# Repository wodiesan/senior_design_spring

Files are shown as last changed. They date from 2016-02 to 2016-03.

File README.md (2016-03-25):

<p align="center">
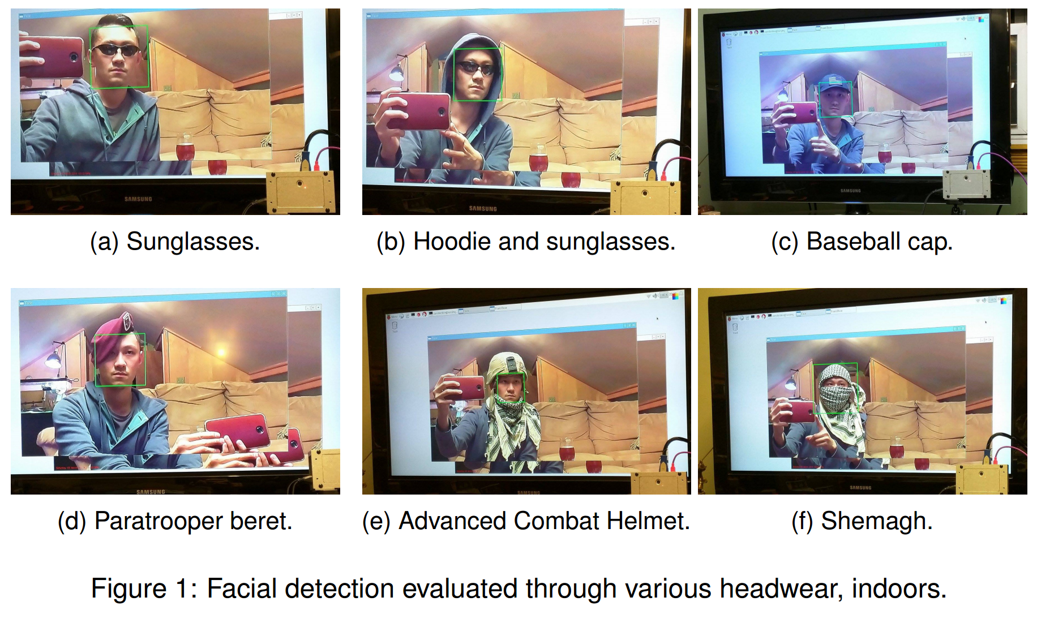
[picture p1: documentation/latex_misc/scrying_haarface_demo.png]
Scrying Logo
  
</p>

# Scrying
A computer vision home surveillance system based on the Raspberry Pi 2. Utilizes the Raspberry Pi CSI camera module and OpenCV framework.

## Front matter
Origin: Senior Electronic Design I Project, Spring 2016  
Advisor: Professor Scott Grenquist  
Deptartment: Electrical Engineering and Technology  
College: Wentworth Institute of Technology  

### What is Scrying?
A low-cost, low-maintenance, Raspberry Pi 2-based home surveillance 
system. This system is designed to allow a homeowner to record digital 
footage. The system includes basic object detection. Recorded videos will
be cataloged by the object type that activated the camera, e.g. human, 
vehicle, and others. The result is a lightweight and scalable home 
surveillance system that remains inexpensive in storage.

#### Main file
The main file is ``scrying.py`` in [scrying](https://github.com/wodiesan/senior_design_spring/tree/master/scrying).

#### Documentation
Visit [documentation](https://github.com/wodiesan/senior_design_spring/tree/master/documentation) for details. All of the technical documents from the semester&mdash;including LaTeX source code&mdash;are in this directory.
The order of the submissions:  

1. [Proposal](https://github.com/wodiesan/senior_design_spring/blob/master/documentation/ChauSze_SeniorDesign1_ProposalRev2.pdf)
2. [Calculations](https://github.com/wodiesan/senior_design_spring/blob/master/documentation/ChauSze_SeniorDesign1_CalcRev2.pdf)
3. [Prototype](https://github.com/wodiesan/senior_design_spring/blob/master/documentation/ChauSze_SeniorDesign1_PrototypeRev1.pdf)
4. Manufacturing: *In progress.*

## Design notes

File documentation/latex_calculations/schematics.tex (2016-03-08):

\section{Schematics}
\label{sec:schem}

\subsection{ATtiny85 Design: First Iteration}
\begin{figure}[H]
    \centering
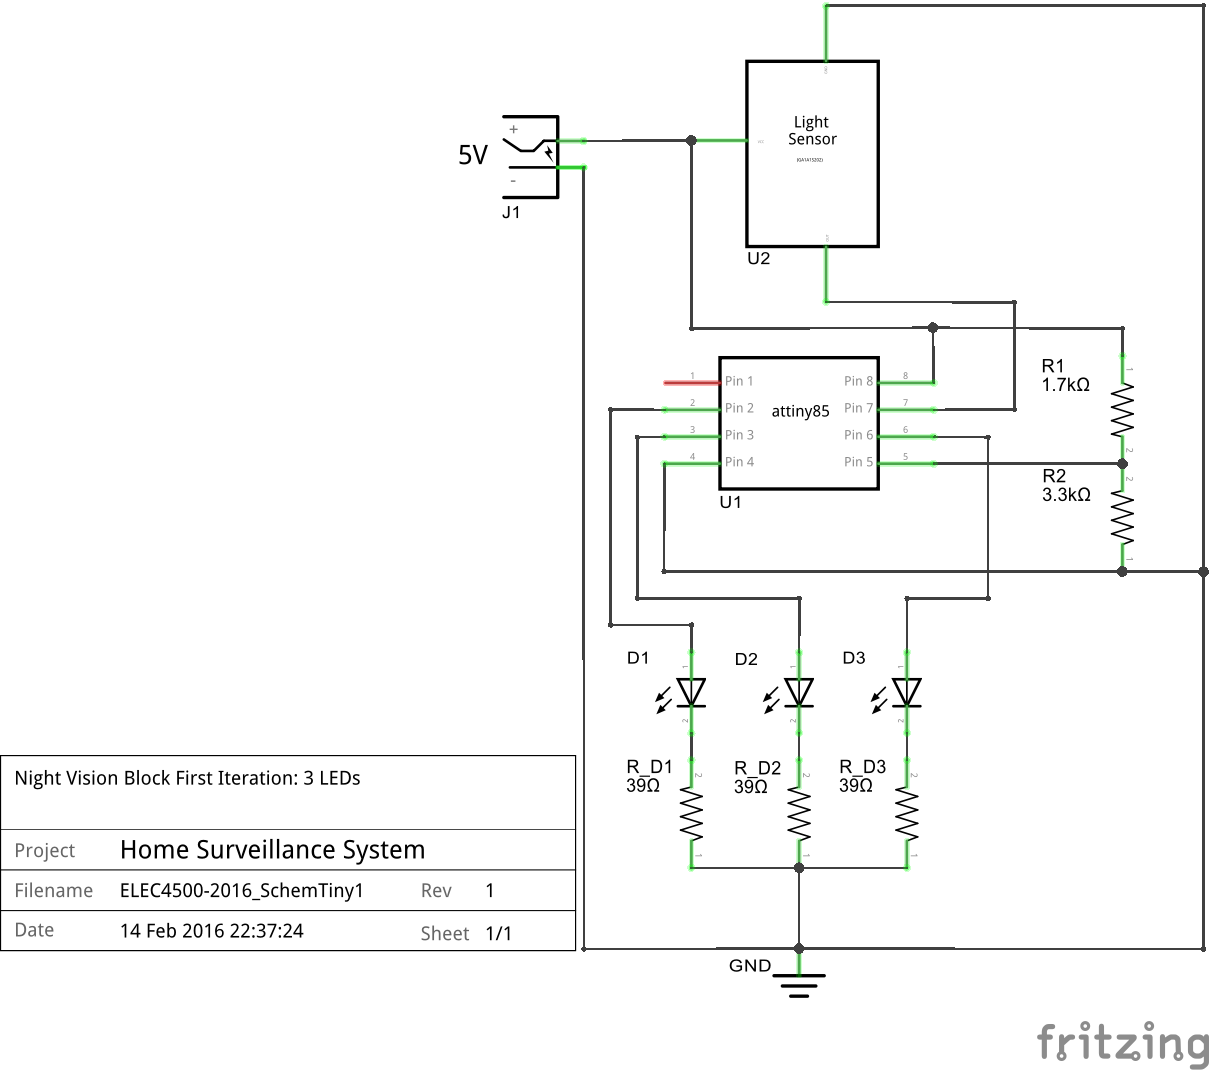
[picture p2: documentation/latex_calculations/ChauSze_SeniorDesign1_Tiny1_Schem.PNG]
    \makebox[\textwidth][c]{}
    \caption{Fritzing schematic of the first ATtiny85 design.}
    \label{tiny1_schem}
\end{figure}

\subsection{ATtiny85 Design: Second Iteration}
\begin{figure}[H]
    \centering
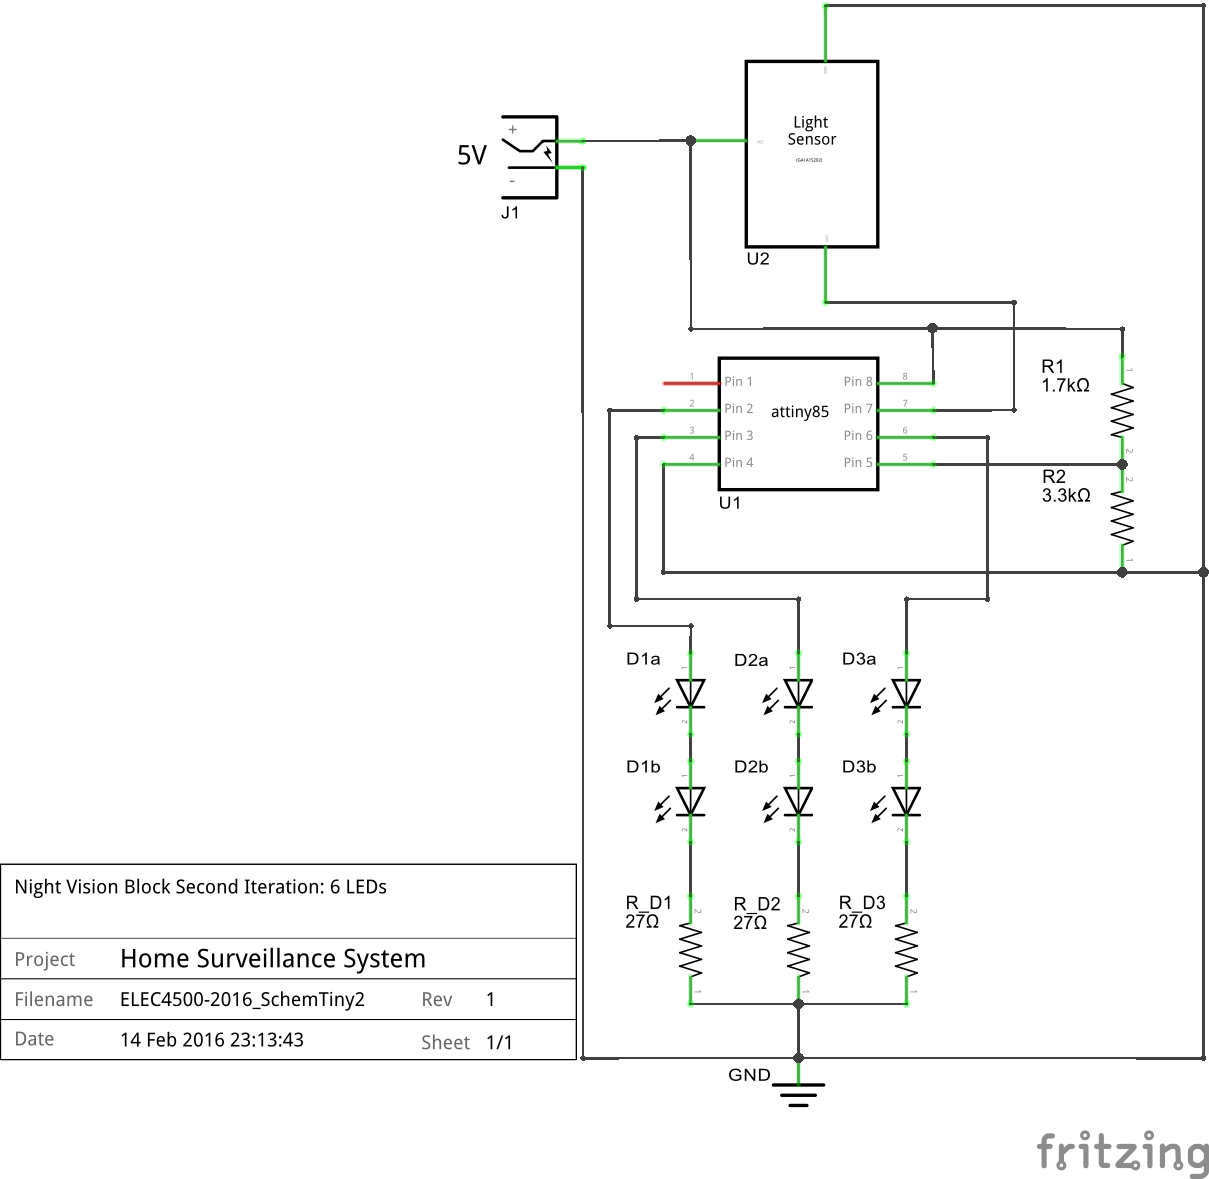
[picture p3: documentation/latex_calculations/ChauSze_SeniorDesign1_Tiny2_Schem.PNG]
    \makebox[\textwidth][c]{}
    \caption{Fritzing schematic of the second ATtiny85 design.}
    \label{tiny2_schem}
\end{figure}

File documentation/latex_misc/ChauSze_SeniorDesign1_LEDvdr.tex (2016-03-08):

\documentclass{article}
\usepackage{tikz}
\usepackage{circuitikz}
\usepackage{siunitx}

\begin{document}
\begin{circuitikz}
\draw (0,2.2)node[anchor=north]{ATtiny85 Pin}
    (0,1.8)node[anchor=north]{5V}
    (0,1)
    node[rground, yscale=-1]{}
    %node[anchor=east] {ATtiny85 Pin: 5V}%(5,0.5) 
    (0,1) -- (0,0)
    to [R={\parbox{1cm}{$R_{IR}$\\\SI{27}{\ohm}}}, mirror] (3,0)
    to [empty led,l_=$LED_{IR}$] (5,0)
    to [empty led,l_=$LED_{IR}$] (7,0)
    (7,0) -- (8,0)
    to (8,-1) node[ground]{};
    
\draw (0,-3)node[anchor=north]{$V_{CC}$}
    (0,-3.4)node[anchor=north]{5V}
    (0,-4.2)
    node[rground, yscale=-1]{}
    to [R={\parbox{1cm}{$R_{1}$\\\SI{1.7}{\kilo\ohm}}}, mirror] (0, -6)
    to[short, -*](0,-6.5)
    to [R={\parbox{1cm}{$R_{2}$\\\SI{3.3}{\kilo\ohm}}}, mirror] (0, -9)
    to (0,-9) node[ground]{}
    (0,-6.5)to[short,-o](-2,-6.5) node[anchor=east]{$V_{o}$};
\end{circuitikz}
\end{document}

%\usepackage[american voltages,siunitx]{circuitikz}

%\begin{document}

%\begin{circuitikz}
%   \draw (0,0) to [R={\parbox{1cm}{$R_{IR}$\\\SI{39}{\ohm}}}, mirror]  (3,0);  
%   \draw (3,0) to [empty led,l=IR] (5,0);
%  \draw (0,-0.5) -- node[anchor=north,align=center] {\SI{5}{V}  \\ ATtiny85 Pin } (0,0.5);
%  \draw (5,-0.5) --  node[anchor=south] {VCC} (5,0.5)  node[anchor=west] {\SI{5}{V}};
%\end{circuitikz}

%\end{document}

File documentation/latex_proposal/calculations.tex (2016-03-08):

\section*{Calculations}
\label{sec:calc}
% CHANGE GB TO 1073741824 BYTES!!!

\subsection{Storage}

Storage requirements for 24 hours of 720p video data (.mp4):
\begin{equation*}
\begin{split}
Continual & = \left(\frac{24 \ hr}{1 \ day}\right)\left(\frac{60 \ min}{1 \ hr}\right)\left(\frac{60 \ sec}{ 1 \ min}\right)\left(\frac{17 \ mbit}{1 \ sec}\right)\left(\frac{1 \ byte}{8 \ bit}\right)\left(\frac{1 \ GB}{1737441824 \ byte}\right) \\
& = 170.99 \ \frac{GB}{day}
\end{split}
\end{equation*}

By limiting the active recording to moments where objects are detected, this storage requirement can be significantly lowered. Taking a theoretical family of 4 and a single dog, we can calculate for a minimum duration that the RPi2 is expected to record in 24 hours: 

\begin{table}[H]
\centering
\caption{Known \glspl{sighting} during an average 24 hour day for a front door camera.}
\label{floor_table}
\begin{tabular}{@{}lcccc@{}}
\toprule
Type     & Qty & Duration (min) & Sighting/24 hr & Total  \\ \midrule
Person   & 4   & 1              & 2               & 8      \\
Dog      & 1   & 1              & 2               & 2      \\
Delivery & 2   & 1              & 1               & 2      \\ \midrule
         &     &                &                 & 12 min
\end{tabular}
\end{table}

With a minimum recording duration of 12 minutes based on the expected sightings (detected objects), the floor data requirements per 24 hours becomes:

\begin{equation*}
\begin{split}
Floor \ & = \left(\frac{12 \ min}{1 \ day}\right)\left(\frac{60 \ sec}{ 1 \ min}\right)\left(\frac{17 \ Mbit}{1 \ sec}\right)\left(\frac{1 \ byte}{8 \ bit}\right)\left(\frac{1 \ GB}{1737441824 \ byte}\right) \\
& = 0.000014254 \ \frac{GB}{day}\Rightarrow 0.014254 \ \frac{MB}{day} \Rightarrow 14.254 \ \frac{KB}{day}
\end{split}
\end{equation*}

\subsection{Analog Light Sensor}

\begin{equation*}
\begin{split}
    \log\left(I_{O}\right) &= mx + b \\
    I_{O} &= m\log\left(x\right) + b \\
    I_{O} &= 10\log\left(E_{v}\right)\left[l_{x}\right]
\end{split}
\end{equation*}

The sensor has an output current range of $0\mu A$--$50\mu A$ between $1$ lux--$100000$ lux. The breakout board converts this current into a voltage using a $68K\Omega$ resistor, giving a voltage output of $0V$--$3.4V$. Given the use-case of the light sensor, the $3.4V$ can be approximated to $3.3V$, which is a suitable voltage reference for the RPi2. With the output current range approximated to a voltage range of $0V$--$3.3V$ between $1$ lux--$100000$ lux,

\begin{equation*}
\begin{split}
    log_{i} &= \log\left(l_{x \ MAX} - l_{x \ MIN}\right) \\
    &= \log\left(100000\right) = 5 \\
\end{split}
\end{equation*}

To convert the analog value to a digital value, an 8-bit ADC is used:
\begin{equation*}
    ADC = \frac{log_{i}}{1024 \ steps} = 0.00488
\end{equation*}

Finally, the formula to obtain the final lux output, $l_{xo}$, on the RPi2:

\begin{equation*}
%\begin{split}
    l_{xo} = 10^{raw_{i} \times ADC} = 10^{raw_{i} \times 0.00488}
%\end{split}
\end{equation*}

where $raw_{i}$ is the raw value received by the ADC connected to the RPI2's GPIO.

%\newpage

%\begin{multicols}{2}
%\begin{onehalfspacing}
%\printglossary
%\end{onehalfspacing}
%\end{multicols}

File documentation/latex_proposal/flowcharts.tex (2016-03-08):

\section*{Flowcharts}
\label{sec:flow}
\begin{figure}[H]
    \centering
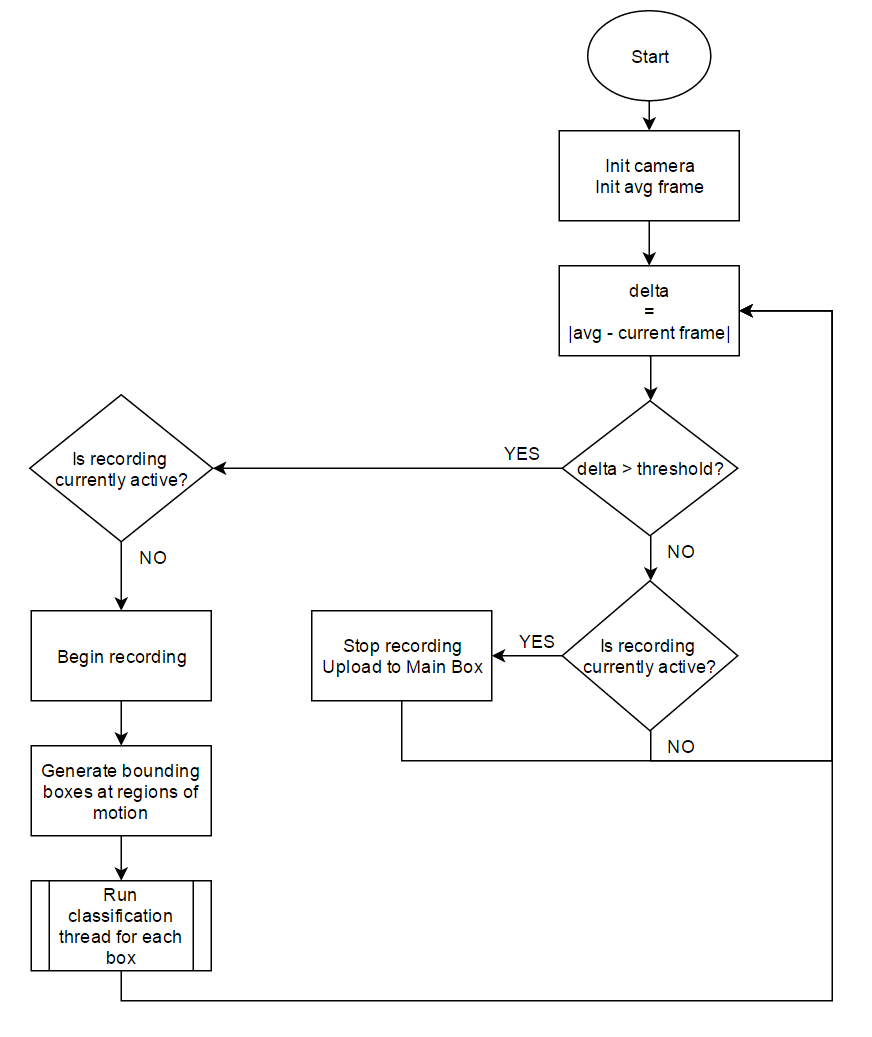
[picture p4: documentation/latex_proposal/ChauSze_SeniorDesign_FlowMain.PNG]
    \makebox[\textwidth][c]{}
    \caption{Flowchart of main program.}
\end{figure}

\begin{figure}[H]
    \centering
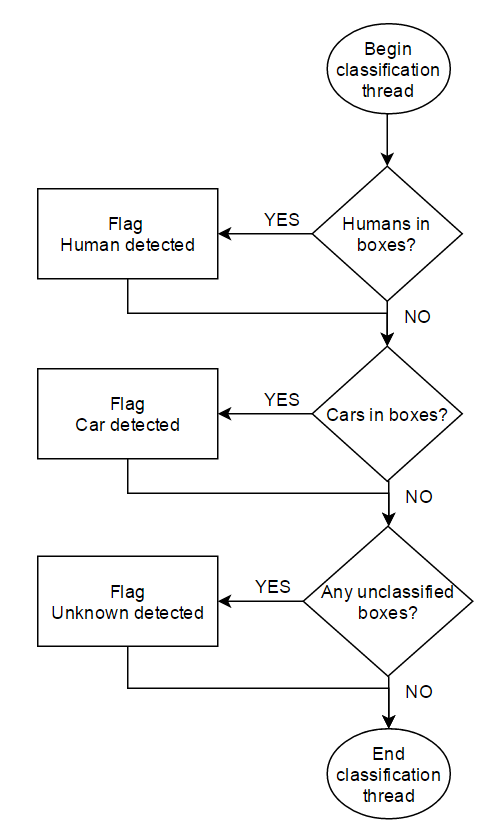
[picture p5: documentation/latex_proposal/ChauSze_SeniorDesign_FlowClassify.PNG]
    \makebox[\textwidth][c]{}
    \caption{Flowchart of classification thread.}
\end{figure}

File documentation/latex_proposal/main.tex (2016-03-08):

\documentclass[12pt]{article}
%\usepackage{fontspec}
%\usepackage[utf8]{inputenc}

\usepackage[margin=1in]{geometry}

\usepackage{graphicx}
\usepackage{amsmath}
\usepackage{float}
\usepackage{xfrac}
\usepackage{subfig}
\captionsetup{belowskip=12pt,aboveskip=4pt}
\usepackage{booktabs}
\usepackage{enumitem}
\usepackage{csquotes}

\usepackage{amsmath}
\usepackage{mathptmx}
\usepackage{helvet}
\renewcommand{\familydefault}{\sfdefault}
\usepackage{verbatim}
\usepackage{gensymb}
\usepackage{setspace}
\usepackage{booktabs}
\usepackage{hyperref}

\usepackage{listings}
\usepackage{color}
\definecolor{lightgrey}{rgb}{0.9,0.9,0.9}
\definecolor{darkgreen}{rgb}{0,0.6,0}

\usepackage{fancyhdr}
\pagestyle{fancy}
\cfoot{Confidential $\mid$ ELEC4500--2016 Rev. 3}
\rfoot{\thepage}

\usepackage{multicol} % Required for splitting text into multiple columns
\setlength{\columnsep}{1cm}
\usepackage[toc]{glossaries}
\usepackage[protrusion=true,expansion=true]{microtype} % Improves spacing
%\usepackage[bf,sf,center]{titlesec} % Required for modifying section titles - bold, sans-serif, centered
%\usepackage{fancyhdr} % Required for modifying headers and footers
%\usepackage{subfiles}

\usepackage[toc,page]{appendix}

\makeglossaries
\input{./glossary.tex}

\begin{document}\thispagestyle{empty}
\pagenumbering{gobble}
\input{./title.tex}
\titleTMB
\newpage
\doublespacing

%\documentclass[12pt]{article}
%\usepackage{graphicx}
%\usepackage{float}
%\usepackage{chngpage}
%\addtolength{\topmargin}{-.5in}
%\textheight = 650pt
%\usepackage{helvet}
%\renewcommand{\familydefault}{\sfdefault}

%\begin{document}

%----------------------------------------------------------------------
% ECO
%----------------------------------------------------------------------
%\vspace{5in}
\begin{table}[H]
\centering
\caption{Revision history.}
\label{table_rev}
\begin{tabular}{@{}llcc@{}}
\toprule
\multicolumn{2}{c}{Senior Electronic Design Proposal}                                                          & \multicolumn{2}{c}{Document Number: ELEC4500--2016} \\ \midrule
Rev. & \multicolumn{1}{l}{Description of Change}                                                               & \S $\ $ Affected & \multicolumn{1}{c}{Originator}   \\
     &                                                                                                         &                  &                                  \\
01   & Initial Release                                                                                         & All              & N. Bamford, R. Chau, A. Martinez \\
     &                                                                                                         &                  &                                  \\
02   & \begin{tabular}[c]{@{}l@{}}General Proofreading\\ Add Glossary and Calculations\\ Add Fig. 6--9, Tbl. \ref{software_req}\\ Revise Fig. 5, Sec. 6, \& References \end{tabular} & All              & R. Chau                          \\
     &                                                                                                         &                  &                                  \\
03   & \begin{tabular}[c]{@{}l@{}}Revise Calculations and Progress Chart\\ Add Flowcharts and Schematics \end{tabular} & All              & N. Bamford, R. Chau, A. Martinez                          \\ \bottomrule
\end{tabular}
\end{table}

\newpage

%----------------------------------------------------------------------
% Abstract and Table of Contents
%----------------------------------------------------------------------
\begin{abstract}\thispagestyle{empty}

A low-cost, low-maintenance, Raspberry \Gls{Pi} 2-based home surveillance system is proposed in this document. This system is designed to allow a homeowner to record digital footage--through low-ambient environments--when a motion threshold is surpassed. The system will include basic human \gls{detection} and object \gls{recognition} features. Recorded videos will be cataloged by the object type that activated the camera, e.g. human, vehicle, and others. This proposed functionality will allow a homeowner to quickly access the database of footage through categorical ``bookmarks'' based on metadata such as date, time, and type of object. The result is a lightweight and scalable home surveillance system that remains inexpensive for storage. 

\end{abstract}

\newpage

\tableofcontents

\newpage

\listoffigures

\listoftables

\newpage

%---------------------------------------------------------------------
% Intro
%---------------------------------------------------------------------
\pagenumbering{arabic}
\section{Problem Statement and Motivation}

Newton, Massachusetts is constantly rated as one of the safest cities in the country; that doesn't mean that crime doesn't occur in the city \cite{newton}. At a localized point of view, one of the engineers on this project--a resident of Newton--accumulated numerous experiences that required the actions of Newton Police Department.  In 2015, the neighbor of this engineer had their house broken into. Thieves kicked in the back door; no one noticed the incident. A few months later, Newton Police was called upon to dust (for fingerprints) a family member’s work van after it was broken into for tools. On the week of Christmas, the garage of another neighbor was broken into overnight. This neighbor was restoring a classic muscle car, and the progress was halted due to stolen rare parts. The worst incident, however, happened a few years ago to the engineer’s friend that was--at the time--living in West Newton. It was a home invasion where the homeowner was tied up at gunpoint, and the thieves tossed her dog into a closet before leaving with jewelry and a safe. To this day the perpetrators were never caught.

The constraints of this device, as determined by informal surveying of Newton homeowners, include the ability to determine if there is an object in motion near a home entrance and to capture a video if this criteria is met. A secondary requirement requested asks for the design of a method to distinguish a human from other objects such as vehicles, and to create a metadata sorting method based on these identification criteria alongside date/time.

The design must take these traits into consideration, or else the system would be severely handicapped and similar to existing commercial systems. The proposed home surveillance system acts as an affordable, mobile, and open source bridge between available, albeit expensive commercial products that either secures empty homes or monitor internal dwellings.

\section{Background}

Literary research for this design split into two distinct avenues: Computer vision and  a novelty investigation into currently available commercial solutions.

\subsection{Computer Vision}

The development of an image processing technique that fits our objectives involves object \gls{recognition} within the field of computer vision. Computer vision is the science of imagery acquisition and interpretation through the use of computers \cite[p.~1-5]{cv}. Object \gls{recognition} describes the task of locating, or recognizing, specific objects within images. In the case of our design, object \gls{recognition} tasks could be incorporated to evaluate initial images arriving from a camera unit for identification of humans or vehicles. The object \gls{recognition} methods that are currently being considered includes \gls{Haar}-like features and \gls{Blob} \gls{detection}.

\subsubsection{Haar-like Features}

\gls{Haar}-like features gets their namesake due to similarities to \gls{Haar} wavelet transforms. It is an object \gls{recognition} algorithm that seeks out common patterns by calculating spatial relationships of information (such as contrast) of the target object \cite[p.~1]{haar}. These patterns that the \gls{Haar}-like algorithm checks are rectangular features that specific objects all have, such as the distance between a human’s eyes, or nose. As human \gls{recognition} is an important feature in the proposed system, a \gls{Haar}-based facial \gls{detection} algorithm will be investigated for the prototype.

\begin{figure}[H]
    \centering
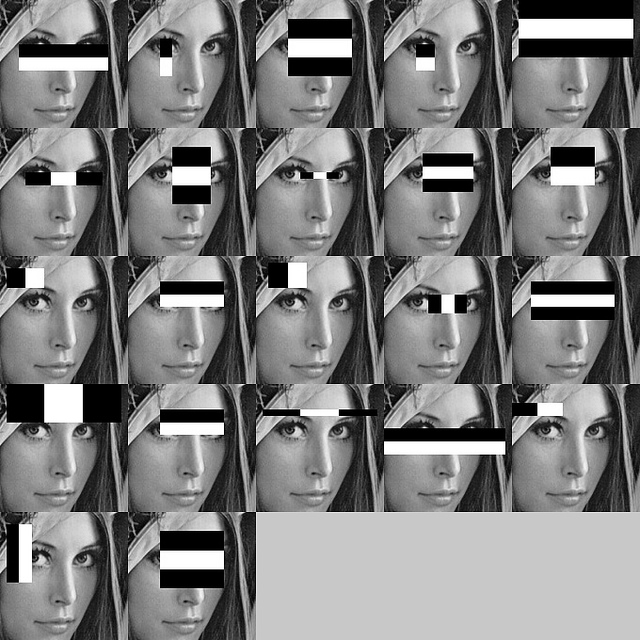
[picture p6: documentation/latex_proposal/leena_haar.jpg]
    \makebox[\textwidth][c]{}
    \caption{\gls{Haar}-like cascade algorithm used to detect human faces.}
\end{figure}

\subsubsection{Blob Detection and Analysis}

\Gls{Blob}s refer to regions of similar pixels in an image. Blob algorithms locates these regions and assigns a category to it based on light or color values \cite[p.~8-18]{blob}. This method requires segmentation of the target image, which involves in the removal of everything outside the region of interest. Depending on the target environment, \gls{Blob} analysis is subject to noise in the form of mis-categorized \gls{Blob}s. The deployment of a \gls{Blob} analysis algorithm would require significant pre-processing of our target object. The advantage of utilizing \gls{Blob} \gls{detection}, however, includes simple identification of large, single-color dominant objects such as vehicles. Due to this capability, \gls{Blob} \gls{detection} will be one of the algorithms used for the prototype. Of concern is the dependability of \gls{Blob} \gls{detection} during low ambient conditions.

%\subsubsection{Other Computer Vision Methods}
% Other potential computer vision methods--such as feature detection methods--will be investigated.

\subsection{Novelty Investigation}

The investigation focused on three major companies with home monitoring commercial solutions. Verizon and Comcast have indoor and outdoor cameras that provide a wireless security system capable with live stream alongside phone apps. This is something that the team aims to pursue (time-dependent). For the proposed system, it is important that the final design remains cost efficient, and the main feature to implement--object \gls{detection} alongside an alert system--is something that current commercial products haven't introduced to the market. Looking at companies that supply commercial home surveillance systems, the team wanted to identify: 

\begin{singlespace}

\begin{itemize}
    \item Patterns of features.
    \item Whether the plan comes with a subscription.
    \item Installation cost, if any.
    \item Cost of the physical equipment.
\end{itemize}

\end{singlespace}

\subsubsection{Verizon}

Verizon offers a home security camera using the brand Canary, a 1080p HD camera able to live stream real time video and audio via a laptop or an app (requires 1 Mbps upload) \cite{verizon}. The camera is equipped with automatic night vision able to viewable with a 25 feet range. The camera is capable of motion \gls{detection} which can be activated and start recording once it senses movement. The sensors are a 3-axis accelerometer with ambient light and capacitive touch. Verizon does not require a personal installation contractor, the camera is an easy 1-2-3 set up and doesn't require a subscription fee.  The app is compatible with IPhone running iOS 7 and higher, and Android 4.0. Cost for everything is \$200 which includes camera, microusb cable, guide, and setup cable.

\begin{figure}[H]
    \centering
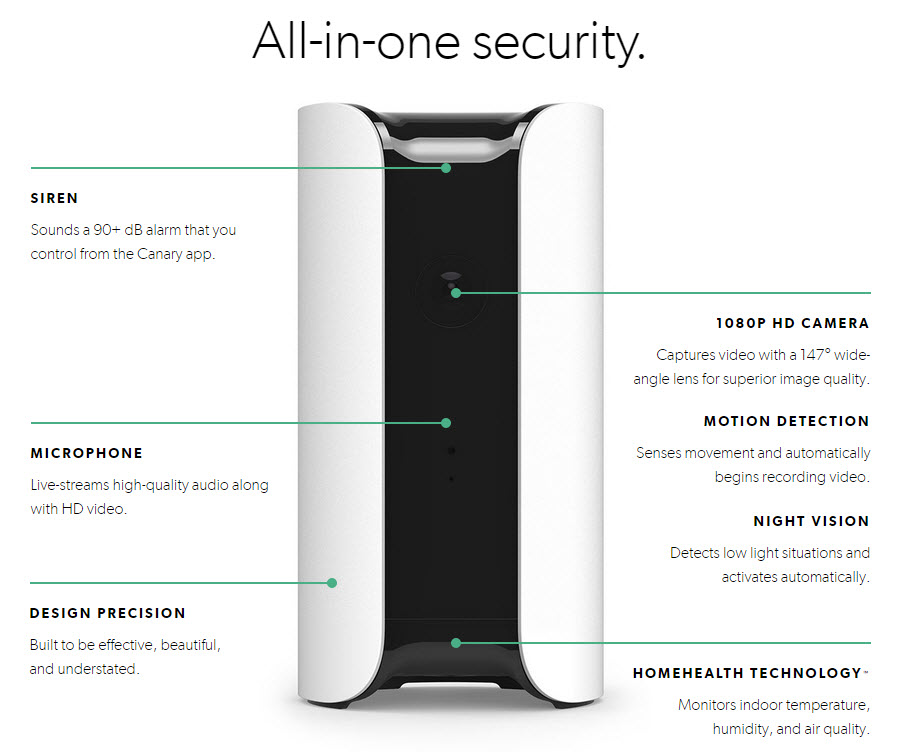
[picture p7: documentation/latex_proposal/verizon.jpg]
    \makebox[\textwidth][c]{}
    \caption{Verizon Canary system.}
\end{figure}

\subsubsection{Comcast}

Comcast Xfinity Homes offers a home security camera that seems to be smaller in size but is able to be placed outside of your house since it is more weather-proof \cite{comcast}. The camera's features are 720p HD resolution, it has night vision although not specified of the range, supports wifi and has sensor motion as well. Although the features for the camera are vague, it comes with a custom tablet and a keypad where you can control the camera. It is optional to use an app on your phone or a laptop to view live video monitoring in and outside your home. For the pricing, the equipment will cost \$200 not including the \$99 installation fee (depending on where you live). Then there is the subscription fee of \$30 a month, which makes the total cost in a range between \$300 to \$400.

\begin{figure}[H]
    \centering
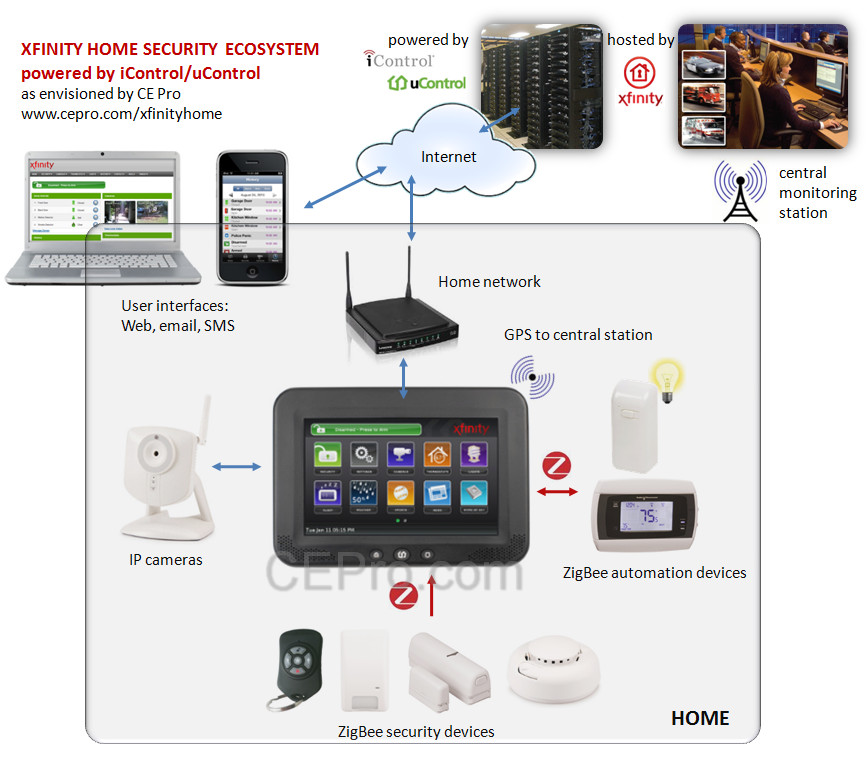
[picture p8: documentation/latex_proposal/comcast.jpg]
    \makebox[\textwidth][c]{}
    \caption{Comcast Xfinity Homes system.}
\end{figure}

\subsubsection{ADT}

ADT Security offers a home surveillance camera called the ADT Pulse Camera, it's a wireless day/night camera \cite{adt}. The camera is equipped with video motion \gls{detection}, a light sensor for night vision, and the camera can capture images that can be viewed online. The security system use their own encrypted wifi accessed through WPA2. The downfall of this camera is you are not able to deliver or store audio when recording the device. The device is also capable of high/low temperature monitoring, light control, climate control, small appliance management and remote access. When it comes to the pricing the installation charge is \$99, comes with a 3 year monitoring agreement that is \$36.99 per month, which is an added total of \$1,331.64. 

\begin{figure}[H]
    \centering
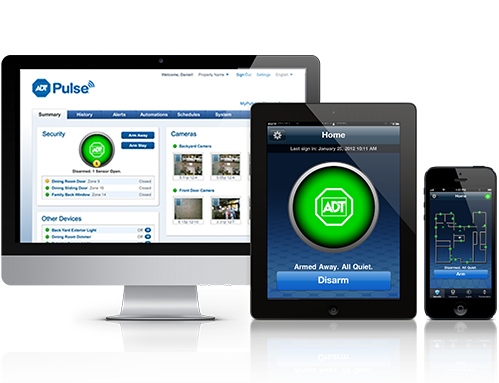
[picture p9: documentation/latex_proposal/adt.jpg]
    \makebox[\textwidth][c]{}
    \caption{ADT Pulse system.}
\end{figure}

\section{Proposed Solution}

\begin{figure}[H]
    \centering
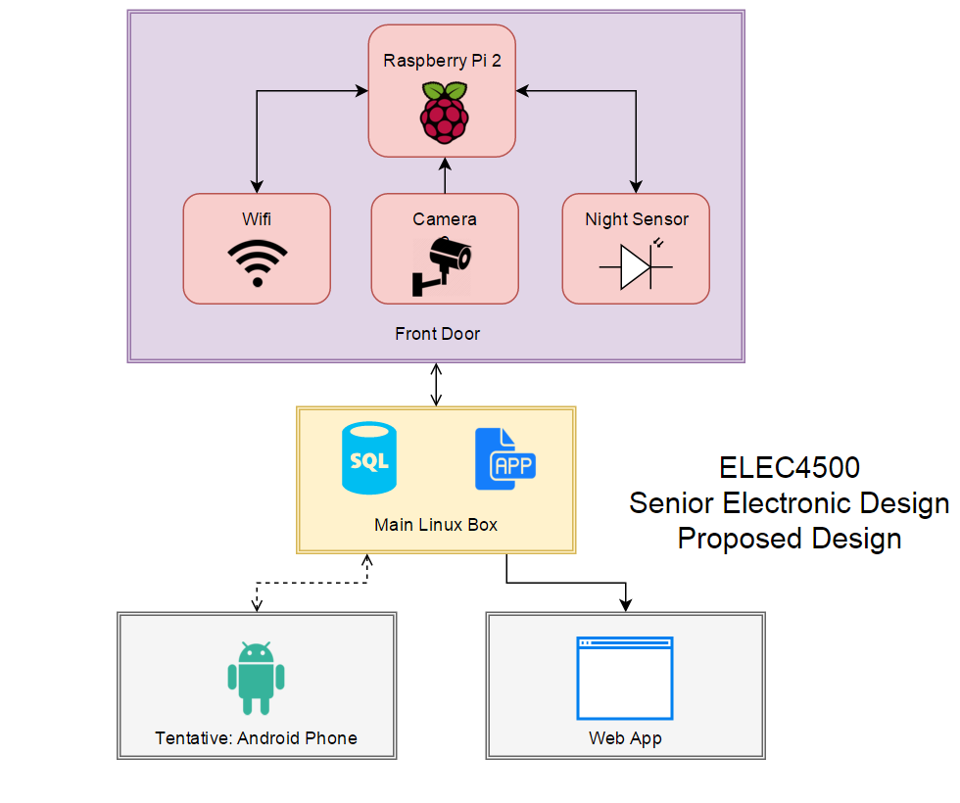
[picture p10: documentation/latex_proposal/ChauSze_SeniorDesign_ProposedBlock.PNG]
    \makebox[\textwidth][c]{}
    \caption{High level block diagram of proposed monitoring system.}
\end{figure}

\begin{table}[H]
\centering
\caption{Minimum software requirements for proposed solution.}
\label{software_req}
\begin{tabular}{@{}lllll@{}}
\toprule
Technology & Version & Type                              & License                    \\ \midrule
Raspbian   & Jessie  & Raspberry Pi Linux OS Distro      & GPLv2                      \\
Debian     & Jessie  & Desktop Linux OS Distro           & DFSG-Compliant             \\
Apache     & 2.4.18  & Web Server                        & Apache 2.0                 \\
MySQL      & 5.7.11  & Relational DB Management System   & GPLv2                      \\
Python     & 2.7     & General Purpose Language          & Python Software Foundation \\
OpenCV     & 3.0.0   & Computer Vision Library           & BSD                        \\
Plotly     & 1.9.5   & Data Visualization Python Library & MIT                        \\ \bottomrule
\end{tabular}
\end{table}

\subsection{Website Mockups}
\begin{figure}[H]
    \centering
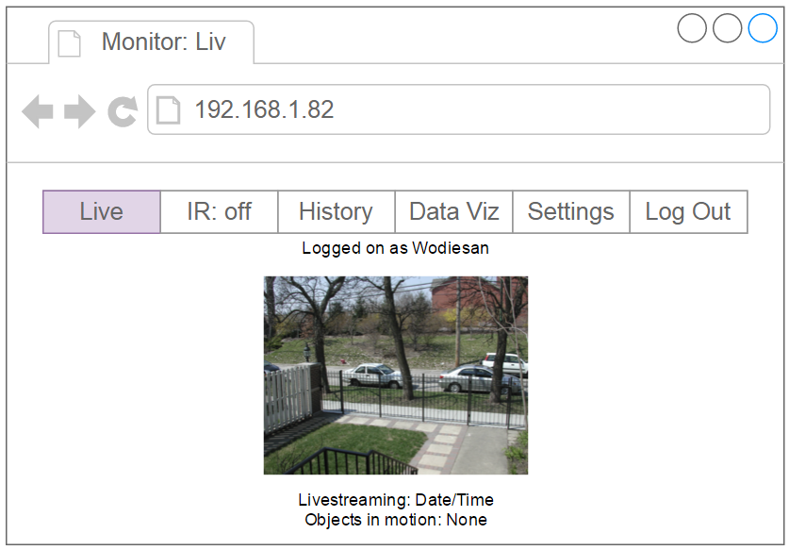
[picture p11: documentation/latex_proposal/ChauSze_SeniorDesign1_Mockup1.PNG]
    \makebox[\textwidth][c]{}
    \caption{Website mockup: \gls{livestream}, daytime.}
\end{figure}

\begin{figure}[H]
    \centering
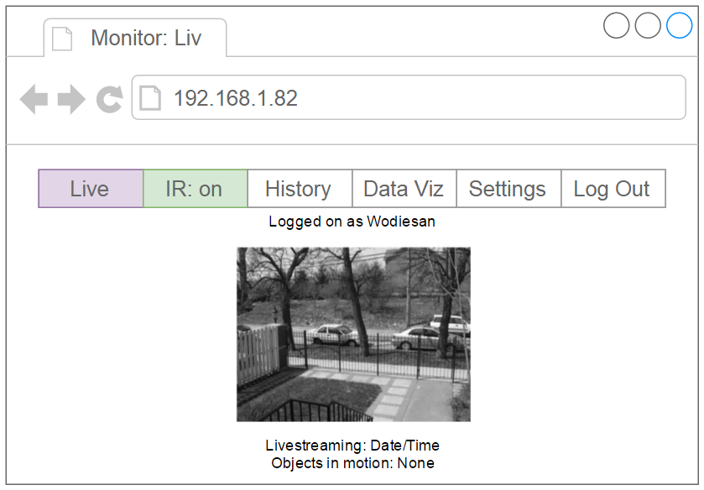
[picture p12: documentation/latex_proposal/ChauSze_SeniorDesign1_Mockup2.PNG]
    \makebox[\textwidth][c]{}
    \caption{Website mockup: \gls{livestream}, nighttime.}
\end{figure}

\begin{figure}[H]
    \centering
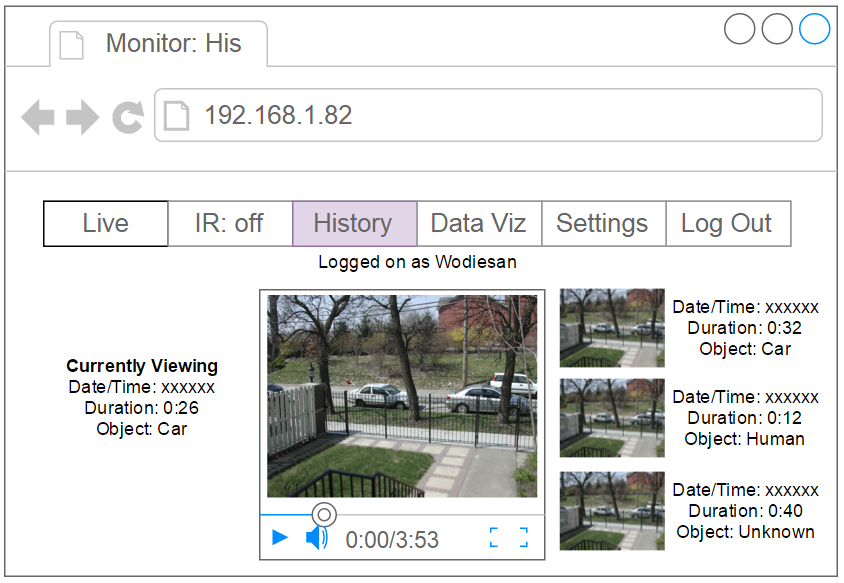
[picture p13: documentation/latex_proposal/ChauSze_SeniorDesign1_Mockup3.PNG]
    \makebox[\textwidth][c]{}
    \caption{Website mockup: History of detected objects.}
\end{figure}

\begin{figure}[H]
    \centering
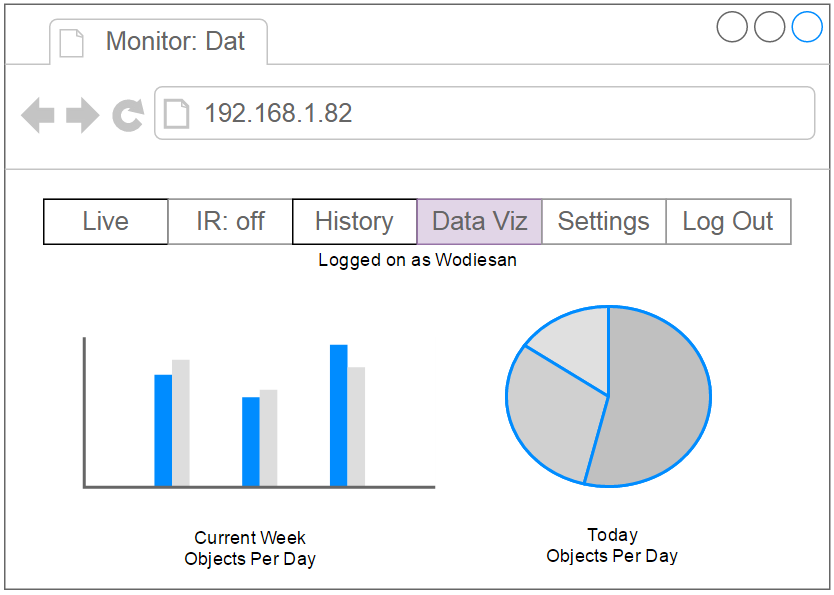
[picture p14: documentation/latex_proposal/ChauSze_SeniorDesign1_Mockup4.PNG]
    \makebox[\textwidth][c]{}
    \caption{Website mockup: Data visualization.}
\end{figure}

\subsection{Technology Selection and Rationale}

In the spirit of universal access to the general public, the proposed system focuses on the utilization of \gls{open source} hardware and software. As such, the Raspberry \Gls{Pi} 2 Model B--a single-board computer--was chosen as the platform for the proposed system. The software architecture will primarily focus on the \Gls{SimpleCV} framework. Simple Computer Vision, officially \Gls{SimpleCV}, is a collection of libraries and algorithms written in Python used for computer vision applications \cite{simplecv}. This \gls{open source} framework allows the Pi to access an attached camera unit and apply object \gls{recognition} tasks to the extracted images. The combination of \Gls{SimpleCV} and the Pi means that Python, the official language for both entities, will be the programming language of choice for the overall system.

\begin{figure}[H]
    \centering
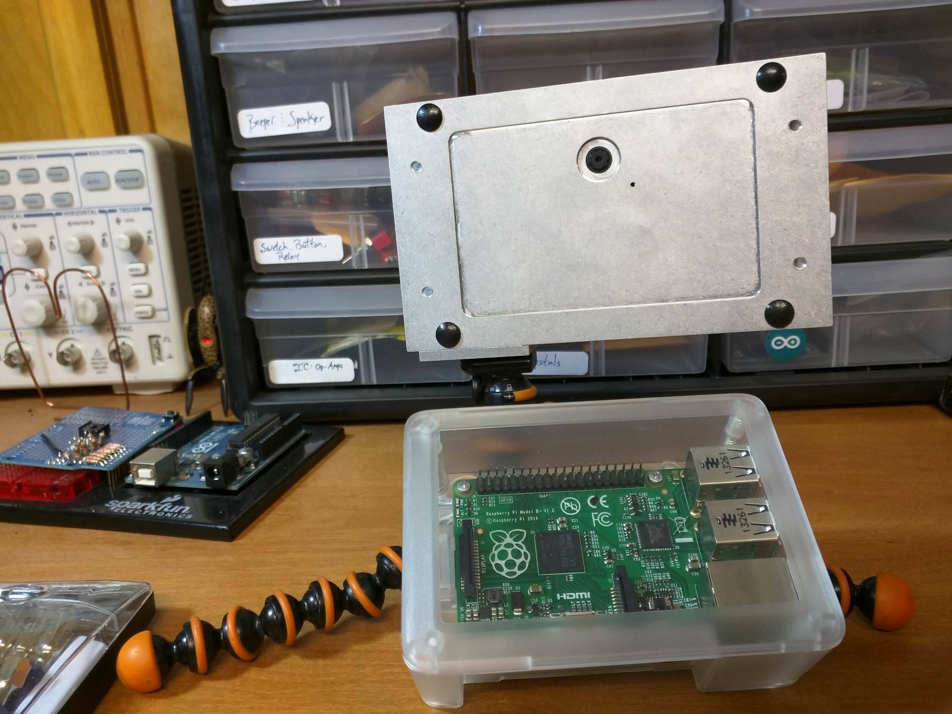
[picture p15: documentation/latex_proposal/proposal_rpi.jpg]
    \makebox[\textwidth][c]{}
    \caption{Raspberry Pi 2 Model B (top) encased with a camera module.}
\end{figure}

\begin{table}[H]
\centering
\caption{Raspberry Pi 2 specifications.}
\label{fig_spec}
\begin{figure}[H]
    \centering
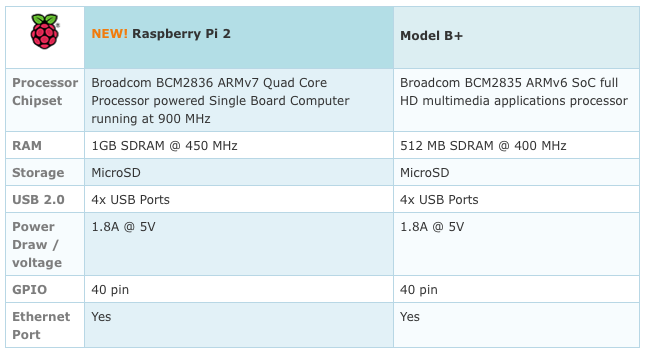
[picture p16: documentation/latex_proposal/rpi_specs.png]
    \makebox[\textwidth][c]{}
    %\caption{LAMP architecture for web application.}
\end{figure}
\end{table}

The web platform will utilize a basic \Gls{LAMP} architecture on a separate Linux box for prototyping purposes.

\begin{figure}[H]
    \centering
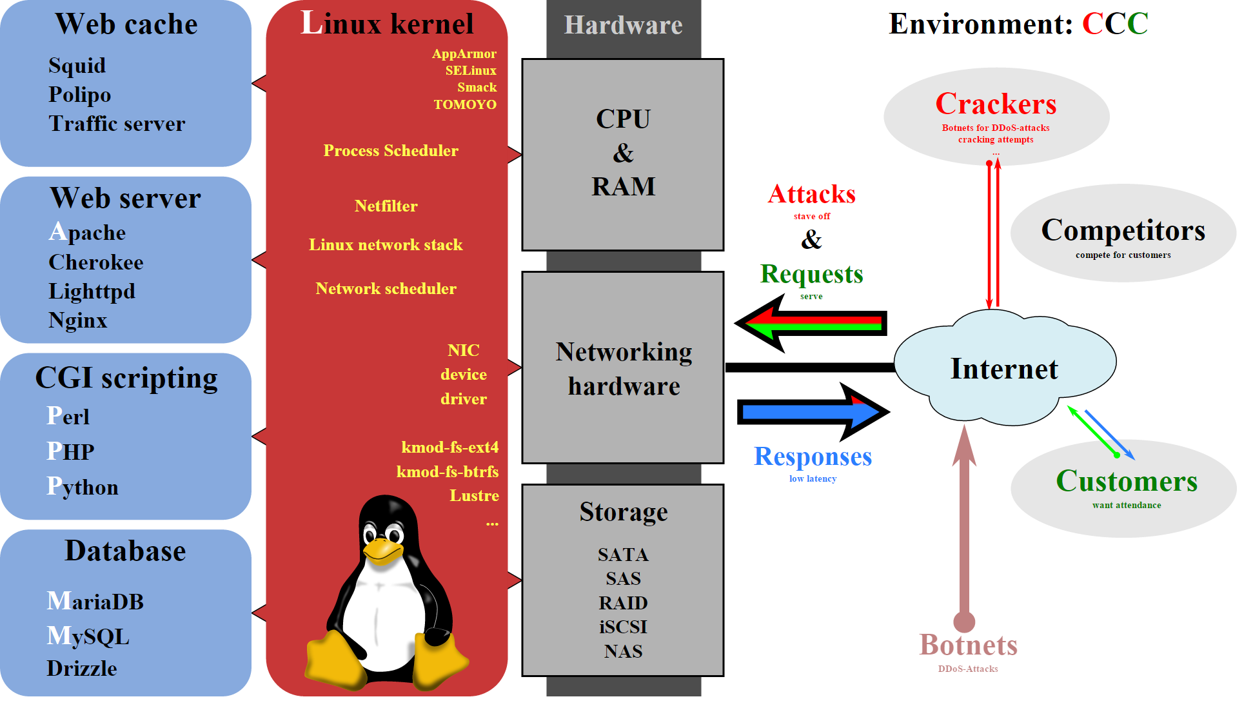
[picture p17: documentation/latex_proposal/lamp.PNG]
    \makebox[\textwidth][c]{}
    \caption{\Gls{LAMP} architecture for web application.}
\end{figure}

\subsection{Feature Comparison of Commercial Systems}

\begin{table}[H]
\centering
\caption{Comparison of major features from commercial systems.}
\label{table_features}
\begin{tabular}{@{}lccc@{}}
\toprule
Feature                 & \multicolumn{1}{l}{ADT} & \multicolumn{1}{l}{Comcast} & \multicolumn{1}{l}{Verizon} \\ \midrule
Weatherproof Camera     &                         & x                           &                             \\
Nightvision             & x                       & x                           & x                           \\
HD Quality              &                         & x                           & x                           \\
Motion \Gls{detection}        & x                       & x                           & x                           \\
\Gls{livestream}              & x                       & x                           & x                           \\
Custom Notifications    & x                       &                             &                             \\
Subscription Fee        & {\color{red}x}                       & {\color{red}x}                           &                             \\
Contractor Installation & {\color{red}x}                       & {\color{red}x}                           &                             \\ \bottomrule
\end{tabular}
\end{table}

As shown in the previous section, cable companies use their brand to set up home surveillance security system around the house to make package deals where the camera, the wifi and the applications are already immutable and installed. That is how companies get the upper hand because the majority of customers don't want to do the research; they prefer that everything is easy to set up. In addition, if the homeowner would not have to pay for an installation fee and can find a cheaper subscription, then it would ease the burden of cost. There are multiple projects, gadgets, and devices that can be found online with guides on how to install the equipment. The problem with that is just the variety of different cameras that can confuse a lot of customers on what product to use and what features are important.

\section{Risks and Challenges}

Due to the ambitious nature of the project, a proposed feature, an Android-based application for \gls{livestream}ing, might not be implemented within the allotted time. This feature will be dependant on the duration of time expended for the major features (object \gls{detection} and \{gls{recognition}). The team feels that the creation of a functional prototype with dependable computer vision features and a web-based interface would trump a system with a rushed and buggy features.

\subsection{Ethical Considerations}
Under Massachusetts General Law, Interception of Wire and Oral Communications, it is permitted for a homeowner to record video surveillance of their home so long as the recording contains no audio \cite{audiolaw}. Due to this constraint, the system will not include any method of recording audio.

Condominium owners, however, are subject to Massachusetts General Law Chapter 183A: Condominiums \cite{condolaw}, and as such may or may not have the right to install a surveillance system should it impede in neighboring unit owner's right to privacy \cite{privacylaw}. \footnote{This section does not constitute as legal advice and should not be acted upon as such. Please seek an attorney for clarification on your home surveillance rights.}

\section{Bill of Materials}

\begin{table}[H]
\centering
\caption{Prototyping bill of materials.}
\label{table_bom}
\scalebox{0.95}{
\begin{tabular}{@{}llrrrr@{}}
\toprule
Description                      & Vendor               & \multicolumn{1}{c}{ID} & \multicolumn{1}{c}{Unit Cost} & \multicolumn{1}{c}{Qty} & Ext. Cost \\ \midrule
Raspberry Pi 2 - Model B         & Adafruit             & 2358                   & \$39.95                       & 1                       & \$39.95   \\
Raspberry Pi Camera Board        & Adafruit             & 1367                   & \$29.95                       & 1                       & \$29.95   \\
WiFi 802.11b/g/n Module          & Adafruit             & 814                    & \$11.95                       & 1                       & \$11.95   \\
8GB Class 10 SD/MicroSD          & Adafruit             & 2692                   & \$9.95                        & 1                       & \$9.95    \\
5V 2A Power Supply USB Connector & Adafruit             & 1994                   & \$6.95                        & 1                       & \$6.95    \\
Log-scale Analog Light Sensor    & Adafruit             & 1384                   & \$3.95                        & 1                       & \$3.95    \\
5mm IR LED 940nm                 & Adafruit             & 387                    & \$0.75                        & 10                      & \$7.50    \\
12' ft Micro-USB to USB Cable    & Amazon               & 2185                   & \$6.40                        & 1                       & \$6.40    \\
SanDisk 32GB microSDHC Class 10    & Amazon               & B010Q57T02                   & \$12.75                        & 1                       & \$12.75    \\
Proto Armour for Raspberry Pi    & MobileApp            & 100052                 & \$35.00                       & 1                       & \$35.00   \\ \midrule
Total Cost:                      & \multicolumn{1}{l}{} & \multicolumn{1}{l}{}   &                               & \multicolumn{1}{l}{}    & \$164.35 
\end{tabular}
}
\end{table}

\section{Division of Labor}

\begin{figure}[H]
    \centering
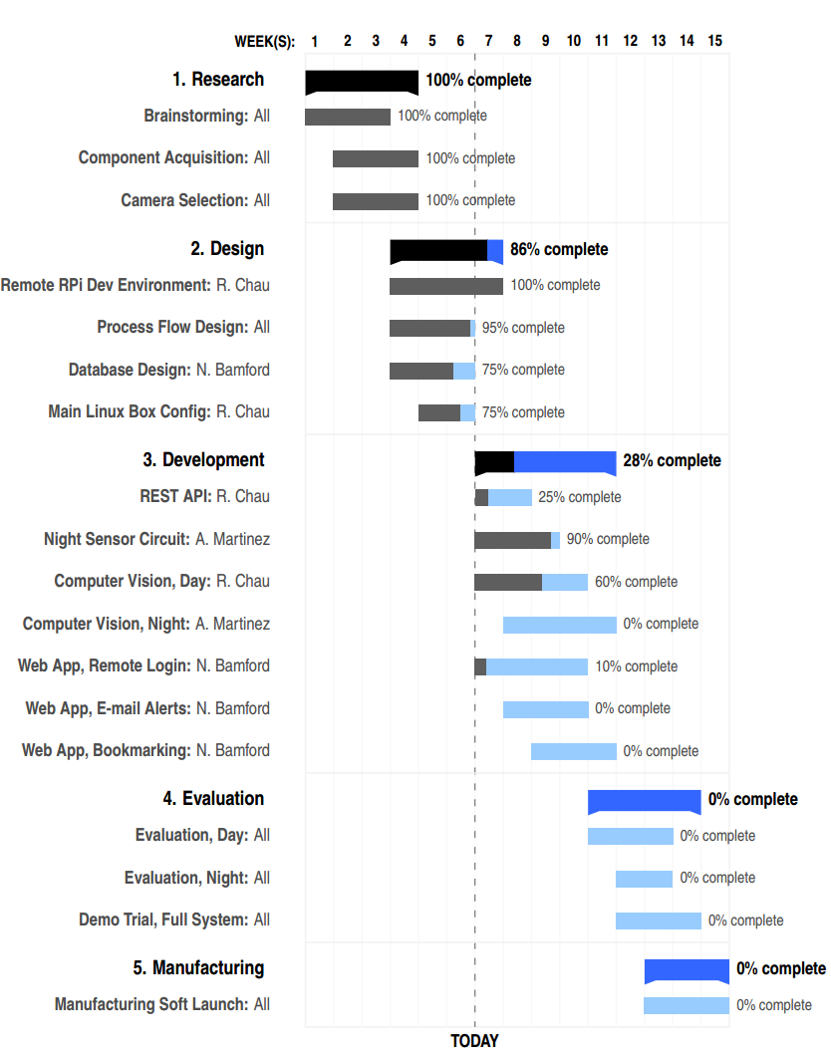
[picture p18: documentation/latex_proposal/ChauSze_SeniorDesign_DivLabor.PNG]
    \makebox[\textwidth][c]{}
    \caption{Progress as of 15 FEB, 2016, broken up by \gls{sprint}s.}
\end{figure}
\newpage

Rather than following the waterfall development model that is prevalent in academia, this project will be largely executed through Scrum-based methodology \cite[pp.~22-32]{scrum}. As such, the completion dates for each task will be mutable. Scrum was chosen by the team due to its iterative and flexible nature; roadblocks such as the one encountered during \emph{TASK 2: Remote Pi Dev Environment} can be bypassed for another task, thereby keeping the team's momentum moving forward \cite{meeting}. 

Each week the team will meet at a minimum of 2 (not counting lecture block), but preferably 3 times in person. Each meeting will begin with a 5 minute maximum \gls{stand-up} where each member will summarize:

\begin{singlespace}

\begin{enumerate}
    \item What was accomplished since the last meeting.
    \item Which task is being worked on.
    \item Roadblocks or backlogs.
\end{enumerate}

\end{singlespace}

Finally, the Monday lecture block will be utilized as the daily \gls{stand-up} meeting, thereby maximizing lab hours for development-related tasks. 

\begin{singlespace}

\subsection{Research Sprint}
\subsubsection{Brainstorming}
\begin{itemize}
\item Research commercial residential security systems.
\item Research computer vision algorithms.
\item Build high-level block diagram.
\item Configure \Gls{ShareLaTeX} repository.
\item Configure \Gls{Google Drive} repository.
\item Configure \Gls{Dropbox} repository.
\end{itemize}

\subsubsection{Component Acquisition}
\begin{itemize}
\item Perform cost analysis and build bill of materials.
\item Purchase components.
\end{itemize}

\subsubsection{Camera Selection}
\begin{itemize}
\item Evaluate RPi camera module and USB-based webcam on RPi 2.
\end{itemize}

\subsection{Design Sprint}
\subsubsection{Remote RPi Dev Environment}
\begin{itemize}
\item Configure virtual environment for project.
\item Set up Python wrappers for \Gls{OpenCV} and \Gls{SimpleCV}.
\item Configure \Gls{VNC} and Adafruit \Gls{WebIDE} for remote access to prototype Raspberry Pi.
\item Configure \Gls{GitHub} repository for version control.
\end{itemize}

\subsubsection{Process Flow Design}
\begin{itemize}
\item Build process flowchart based upon functional requirements.
\item Build website UI flowchart.
\item Build low level block diagrams, as needed.
\end{itemize}

\subsubsection{Database Design}
\begin{itemize}
\item Design entity-relationship database based on the functional requirements.
\end{itemize}

\subsubsection{Main Linux Box Config}
\begin{itemize}
\item Set up Linux Debian.
\item Set up Apache web server.
\item Set up MySQL database.
\end{itemize}

\subsection{Development Sprint}
\subsubsection{REST API}
\begin{itemize}
\item Develop (\Gls{REST}ful) Python \Gls{API} bindings to access \Gls{MySQL} database.
\end{itemize}

\subsubsection{Night Sensor Circuit}
\begin{itemize}
\item Calculate sensor model for light sensor.
\item Build schematic.
\item Breadboard IR LED array.
\end{itemize}

\subsubsection{Computer Vision, Day}
\begin{itemize}
\item Develop motion sensor feature.
\item Develop human classifier--through \Gls{SimpleCV} Library--in Python.
\item Develop car classifier--through SimpleCV Library--in Python.
\end{itemize}

\subsubsection{Computer Vision, Night}
\begin{itemize}
\item Trial daytime computer vision function during low-ambient conditions. Refine as needed.
\end{itemize}

\subsubsection{Web App, Remote Login}
\begin{itemize}
\item Develop a secure method to log into web app.
\end{itemize}

\subsubsection{Web App, E-mail Alerts}
\begin{itemize}
\item Develop the functions that will alert the user of movement.
\item Refine alert constraints to reduce needless alerts.
\end{itemize}

\subsubsection{Web App, Bookmarking}
\begin{itemize}
\item Develop bookmarking system based on database design.
\item Develop user-configurable history page. Pull a still image from each recording and embed--alongside metadata-- the related record. 
\item Develop \gls{livestream}ing by dynamically embedding recordings onto website.
\item Develop charts based on detection history using Google Charts \Gls{API}, \Gls{Plotly}, or another data visualization graphing system with a Python wrapper.
\end{itemize}

\subsection{Evaluation Sprint}
\subsubsection{Evaluation, Day}
\begin{itemize}
\item Trial prototype based on the methods listed in the following section.
\end{itemize}

\subsubsection{Evaluation, Night}
\begin{itemize}
\item Trial prototype based on the methods listed in the following section. 
\end{itemize}

\subsubsection{Demo Trial, Full System}
\begin{itemize}
\item Evaluate complete prototype. Refine as needed.
\item Refactor code base.
\end{itemize}

\subsection{Manufacturing Sprint}
\subsubsection{Manufacturing Soft Launch}
\begin{itemize}
\item Create promotional video using the prototype.
\item Cost analysis for 10,000 units.
\end{itemize}

\end{singlespace}

\section{Evaluation Methods}

As part of the prototyping analysis phase, the system will be trialed during daytime, low ambient, and--weather permitting--heavy snow conditions. The trials will also focus on two major identification categories: Human and Vehicle.

\begin{singlespace}

\subsection{Ambient Conditions}

\begin{enumerate}
    \item Daytime, clear view.
    \item Daytime, snowy conditions.
    \item Low ambient, clear view.
\end{enumerate}

\subsection{Human Identification}

Four types of facial conditions will be used in the trials:

\begin{enumerate}
    \item Human with uncovered hair and face, short hair.
    \item Human with uncovered hair and face, shoulder-length hair.
    \item Human wearing a hoodie.
    \item Human wearing a baseball cap.
\end{enumerate}

\subsection{Vehicle Identification}

Three types of vehicles will be used in the trials:

\begin{enumerate}
    \item Black SUV
    \item White Van
    \item White Sedan
\end{enumerate}

\end{singlespace}

%---------------------------------------------------------------------
% Conclusion
%---------------------------------------------------------------------
\section{Conclusion}
The design outlined in this proposal will allow for the deployment of a low cost, open source device capable of performing the constraints set forth. Careful research analysis and planning in design implementation will be maintained through the entire process in an effort to minimize disturbances to the research subject populations and conditions. Overall cost is reduced by a preference towards open sourced hardware and software. Features that increase usability in the low ambient conditions are also balanced into the product. 

This design can evolve from the initial concepts through meetings with the researchers and prototyping trials. The Home Surveillance System will be able to accomplish data-gathering and metadata categorization of both humans and vehicles with strict identification abilities.

\newpage
\section{Appendix}
\pagenumbering{roman}

%\newpage
\addcontentsline{toc}{section}{\nameref{sec:calc}}
\input{calculations}

\newpage
\addcontentsline{toc}{section}{\nameref{sec:schem}}
\input{schematics}

\newpage
\addcontentsline{toc}{section}{\nameref{sec:flow}}
\input{flowcharts}

%\newpage
%\addcontentsline{toc}{section}{\nameref{sec:db}}
%\input{database}

\newpage
\begin{multicols}{2}
\begin{onehalfspacing}
\printglossary
\end{onehalfspacing}
\end{multicols}

\newpage

\input{glossary}

\addcontentsline{toc}{section}{References}
\input{bibl}

\end{document}

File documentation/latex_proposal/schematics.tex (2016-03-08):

\section*{Schematics}
\label{sec:schem}

Due to anticipated difficulties in driving the IR LEDs, there are two design choices for the system.

\subsection{RPi2 GPIO-based Design}

In this design, an ADC chip is added in order to transfer the data from the lux sensor to the RPi2.

\begin{figure}[H]
    \centering
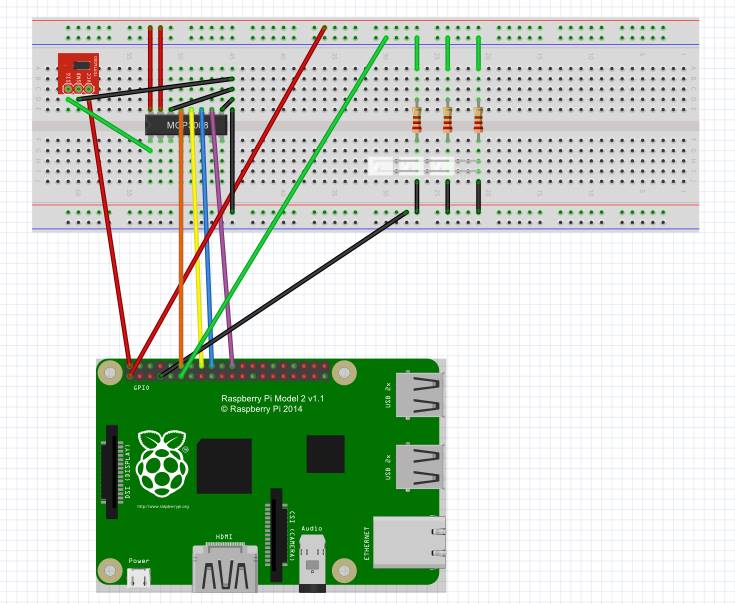
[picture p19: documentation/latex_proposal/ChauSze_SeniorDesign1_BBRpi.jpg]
    \makebox[\textwidth][c]{}
    \caption{Fritzing breadboard diagram of the RPi2 design.}
\end{figure}

\subsection{Arduino-based Design}

The ``Arduino-based design'', in actuality, would be a ATmega series microcontroller design. Currently, the Arduino Uno Rev. 3--based on the ATmega 328--is utilized as a quick evaluation on whether hosting the LEDs on a microcontroller (and subsequent 5V source) would better serve the purposes of night surveillance. 

\begin{figure}[H]
    \centering
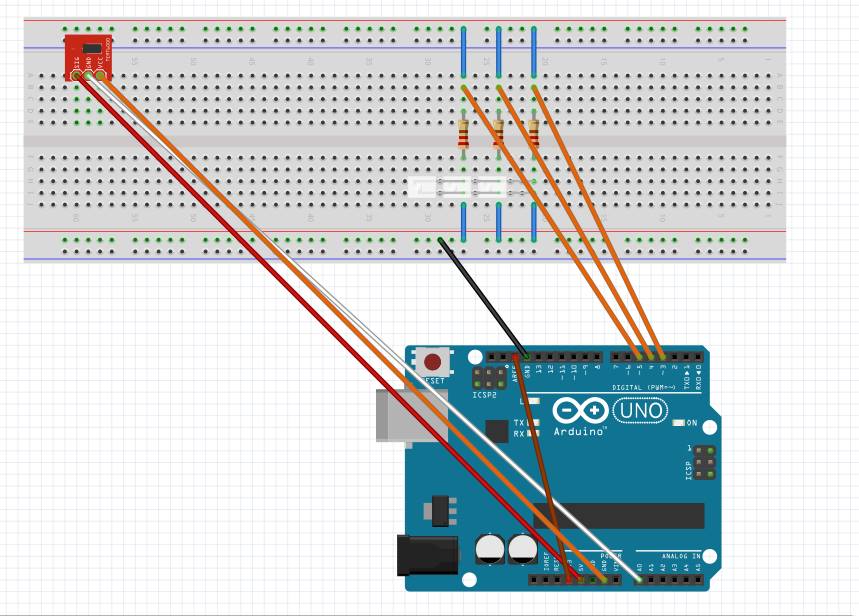
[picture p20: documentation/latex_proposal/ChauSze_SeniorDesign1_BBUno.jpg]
    \makebox[\textwidth][c]{}
    \caption{Fritzing breadboard diagram of the Arduino design.}
\end{figure}

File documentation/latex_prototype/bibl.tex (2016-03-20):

%---------------------------------------------------------------------
% Bibliography
%---------------------------------------------------------------------
%\addcontentsline{toc}{section}{References}
\begin{singlespacing}
\begin{thebibliography}{20}

%\bibitem{mallat} S. Mallat, ``Fourier Kingdom: Properties'', in \emph{A Wavelet Tour of Signal Processing, 2nd ed.}, Chestnut Hill, MA: Academic Press, 1999.

\bibitem{ViolaJones} P. Viola, M. Jones, ``Robust Real-Time Face Detection,'' in \emph{Int. Jour. Computer Vision}, vol. 57.2, pp.~137-154, 2004.

\bibitem{weaved} ``Raspberry Pi - Weaved Inc'', \emph{Weaved Inc.}, 2016. [Online]. Available: http://www.weaved.com/raspberry-pi-remote-connection/. [Accessed: 14MAR2016].

%\bibitem{haarTri} A. Haselhoff, A. Kummert, ``A vehicle detection system based on Haar and Triangle features'', {Intelligent Vehicles Symposium, 2009 IEEE}, Xi'an, pp.~ 261-266, 2009.

%\bibitem{motionHaar} H. Bai, J. Wu, et al, ``Motion and haar-like features based vehicle detection'', \emph{Multi-Media Modelling Conference Proceedings, 2006 12th Int.}, Beijing, pp.~ 4, 2006.

%\bibitem{vehicleFeatures} R. Kostia, ``Video-based traffic monitoring at day and night time: Vehicle features detection and tracking'', in \emph{Proc. 12th International IEEE Conf.}, pp.~285-290, 2009. 

% http://www.cs.utexas.edu/~grauman/courses/spring2008/slides/Faces_demo.pdf

% http://www.cvip.uofl.edu/wwwcvip/education/ECE523/Spring%202011/Lec7.pdf

% https://www.element14.com/community/community/raspberry-pi/raspberrypi_projects/blog/2014/01/24/pi-noir-with-ir-leds

%\bibitem{meeting} Department of Electrical Engineering and Technology. (2016, Feb 1). ``Lecture Meeting: Daily stand-up for project ELEC4500--2016''. Wentworth Institute of Technology, Boston, MA.

\end{thebibliography}
\end{singlespacing}

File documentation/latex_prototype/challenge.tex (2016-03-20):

\section{Challenges and Considerations}
\label{sec:challenge}

%---------------------------------------------------------------------
%           CURRENT DRAW
%---------------------------------------------------------------------
\subsection{Power and USB Current Draw}

It is recommended to power the system with a 5V, 2A microUSB cable power supply. Using a power supply with lower current capabilities will result in instability.

\subsubsection{USB Hub}
In addition to the 2A power supply consideration, end users that plan on attaching unrelated USB devices could potentially experience intermittent wifi connection, amongst other issues. Current draw from various USB devices was examined through the \verb|usb-devices| and \verb|lsusb -v| commands in Raspbian:

\begin{table}[h]
\centering
\caption{Example average current draw of the Home Surveillance System with unrelated USB devices attached to the RPi2 unit.}\label{tab:current}
\begin{tabular}{@{}lr@{}}
\toprule
Device                      & Current Draw      \\ \midrule
Raspberry Pi                & 750mA             \\
Camera Module               & 100mA--260mA      \\
Wifi Dongle                 & 50mA--100mA       \\
Keyboard and Mouse Combo    & 98mA              \\
External Hard Drive         & 750mA             \\\bottomrule
\end{tabular}
\end{table}

While it might seem okay to run the RPi2 off of a 5V, 2A power supply, this might not be the case depending on additional USB devices unrelated to the home surveillance system. For example, a user could attach some or all of the USB devices listed in Table \ref{tab:current}. The result is an average 1.96A current draw. Without a powered hub, this setup would risk wifi stability when the user leverages the VNC server. A powered USB hub isn't necessary at the current design iteration, however, it is advised to consider one if there are plans to run other USB-based, current-hungry devices on the RPi2 unit.

%---------------------------------------------------------------------
%           CURRENT LIMITER
%---------------------------------------------------------------------
\subsubsection{USB Current Limiter}
The RPi2 includes a current limiter for USB peripherals to reduce brown-outs on the main supply. The total current drawn by USB devices defaults to 600mA, but this can be increased to 1.2A, doubling the default allowance. The RPi2 proof of concept unit \verb|scrying| has been adjusted for this increase. This adjustment is found in \verb|/boot/config.txt|:

\begin{centerverbatim}
max_usb_current=1
\end{centerverbatim}

Increasing this current limit seems to result in a more stable wireless connection for remote viewing through VNC. If power-related issues occur (as indicated by the flickering red power LED on the RPi2), commenting the line out of the file should be the first step in debugging the issue.

%---------------------------------------------------------------------
%           SECURITY
%---------------------------------------------------------------------
\subsection{Security}

The current design relies on VNC to access the RPi2 desktop remotely. The initial process to VNC from an outside network required port forwarding to a specific TCP port. This method presents a security vulnerability; by default, the transmitted data isn't encrypted. This becomes a concern when accessing the system outside of the home network.

Weaved, a cloud-based network platform, was chosen as a safeguard for secure access through VNC and HTTP \cite{weaved}.

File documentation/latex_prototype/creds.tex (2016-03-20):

\section{Prototype Specifications and Credentials}
\label{sec:creds}

\begin{table}[H]
\centering
\caption{Software utilized within prototype.}
\label{req}
\begin{tabular}{@{}lllll@{}}
\toprule
Technology & Version   & Type                              & License                     \\ \midrule
Raspbian   & Jessie    & Raspberry Pi Linux OS Distro      & GPL v2                      \\
Python     & 2.7       & General Purpose Language          & Python Software Foundation  \\
OpenCV     & 3.0.0     & Computer Vision Library           & BSD                         \\
TightVNC   & 1.3.9-6.5 & Virtual Computing Network         & GPL v2                      \\
Weaved     & 1.3-02    & Network Managing Platform         & GPL v2                      \\\bottomrule
\end{tabular}
\end{table}

\begin{table}[H]
\centering
\caption{Credentials to the prototype system.}
\label{credentials}
\begin{tabular}{@{}ll@{}}
\toprule
Name        & Type                \\ \midrule
scrying     & RPi2 Hostname       \\
constantine & RPi2 Username       \\
cv          & Virtual Environment \\\bottomrule
\end{tabular}
\end{table}

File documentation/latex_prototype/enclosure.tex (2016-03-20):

\section{Enclosures}
\label{sec:enclosure}

During the Proposal Phase the design included a MobileApp Systems Proto Armour Enclosure for the RPi2. During cost analysis, it was quickly concluded that--while beneficial at the proof of concept stage--this component would not meet the requirements for a production-level product. The choice of the Proto Armour was based on the enclosure's robust aircraft-grade aluminum, support for the camera module, and numerous mounting holes at each side of the case. The Proto Armour, however, wasn't designed to be weatherproof. In addition, the cost per enclosure at \$45 per enclosure represents close to 30\% of the direct materials cost per unit. This high cost disqualified the Proto Armour Enclosure for purposes beyond proof of concept designs.

\begin{figure}[H]
    \centering
    \begin{subfigure}[b]{0.475\textwidth}
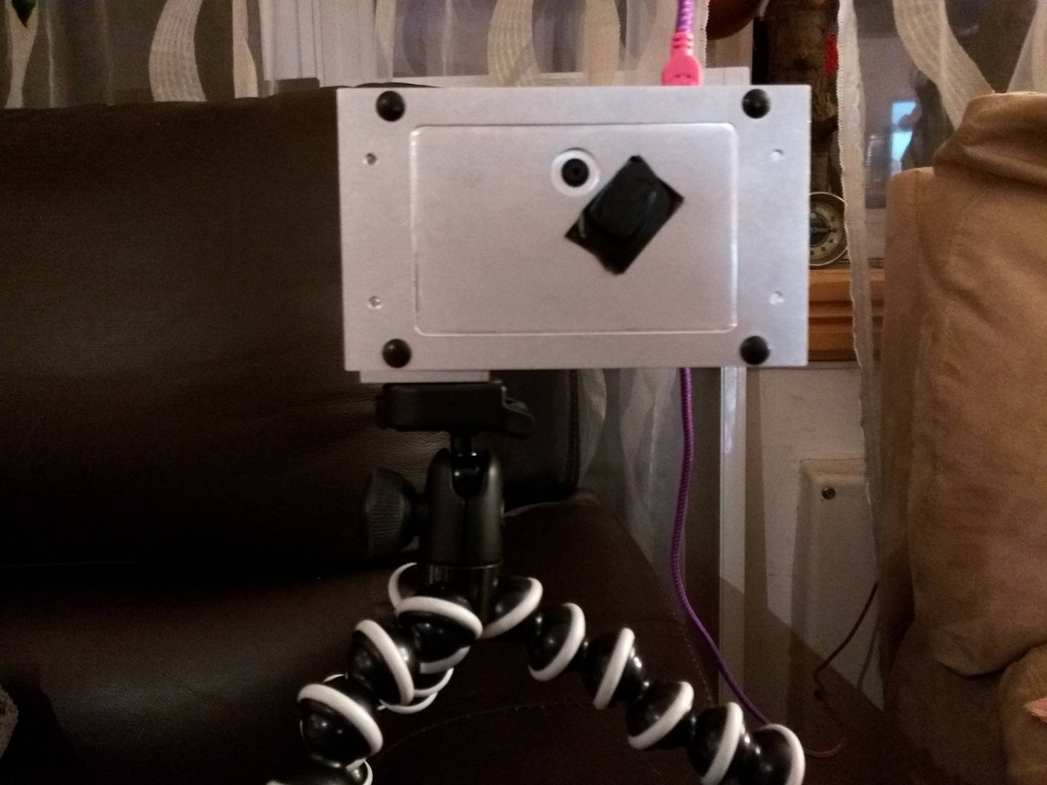
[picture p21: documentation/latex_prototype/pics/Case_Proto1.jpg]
        
        \caption{External view.}
        \label{fig:ProtoCase1}
    \end{subfigure}
    ~ %add desired spacing between images, e. g. ~, \quad, \qquad, \hfill etc. 
      %(or a blank line to force the subfigure onto a new line)
    \begin{subfigure}[b]{0.475\textwidth}
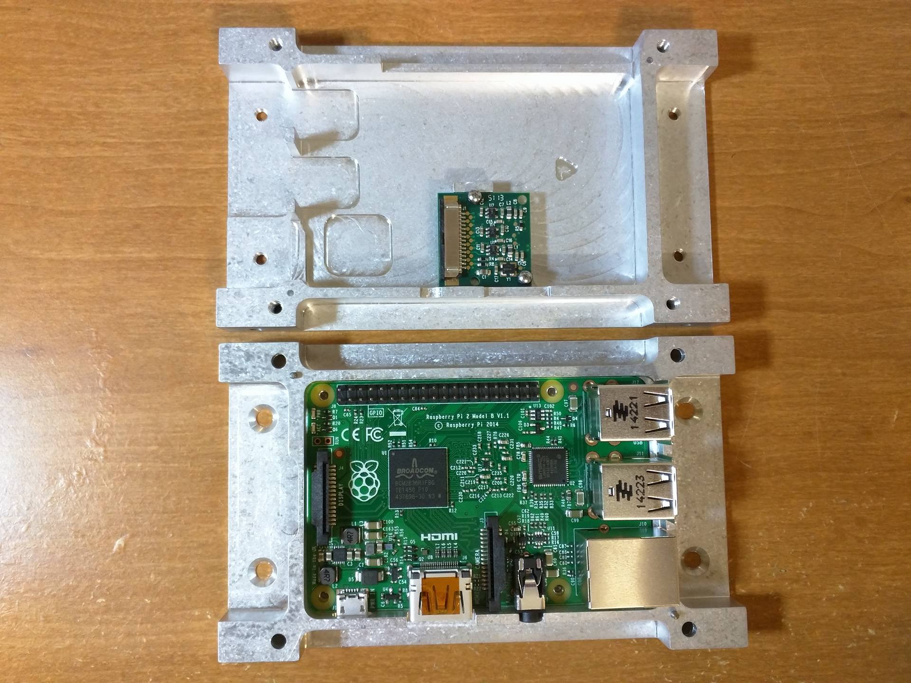
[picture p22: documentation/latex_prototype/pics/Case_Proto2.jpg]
        
        \caption{Internal view.}
        \label{fig:ProtoCase2}
    \end{subfigure}
    \caption{Proto Armour Enclosure by MobileApp Systems.}\label{fig:ProtoCase0}
\end{figure}

%---------------------------------------------------------------------
%           CCTV
%---------------------------------------------------------------------
\subsection{CCTV Weatherproof Enclosure}

A strong contender was a generic 15 in. length CCTV Weatherproof Enclosure. This enclosure is primarily aluminum is sealed with heavy duty rubber to prevent water intake. Priced around \$25, this enclosure is an improvement from the Proto Armour. This candidate, however, was rejected for several reasons:

\begin{singlespace}
\begin{enumerate}
    \item Enclosure is larger and heavier than necessary for the system, making inconspicuous installation unlikely.
    \item The large viewing window and the distance where the camera is mounted increases light pollution from the surrounding environment as well as the RPi2 diagnostic LEDs.
    \item LEDs inside: The viewing window isn't wide enough for both the camera module and Night Vision board.
    \item LEDs outside: A secondary enclosure will be required to custom mount onto the CCTV enclosure.
    \item While not required, additional enclosures for the RPi2 and the camera module would be recommended, thereby increasing the cost to the level of the Proto Armour Enclosure.
\end{enumerate}
\end{singlespace}

\begin{figure}[H]
    \centering
    \begin{subfigure}[b]{0.475\textwidth}
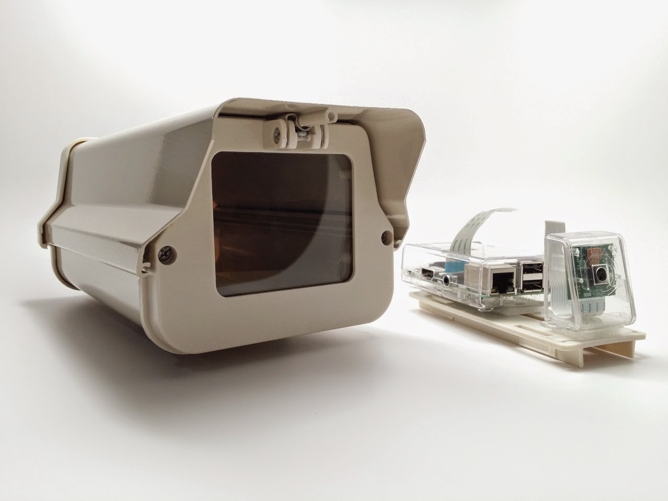
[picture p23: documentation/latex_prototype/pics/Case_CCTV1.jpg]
        
        \caption{External view.}
        \label{fig:CCTVCase1}
    \end{subfigure}
    ~ %add desired spacing between images, e. g. ~, \quad, \qquad, \hfill etc. 
      %(or a blank line to force the subfigure onto a new line)
    \begin{subfigure}[b]{0.475\textwidth}
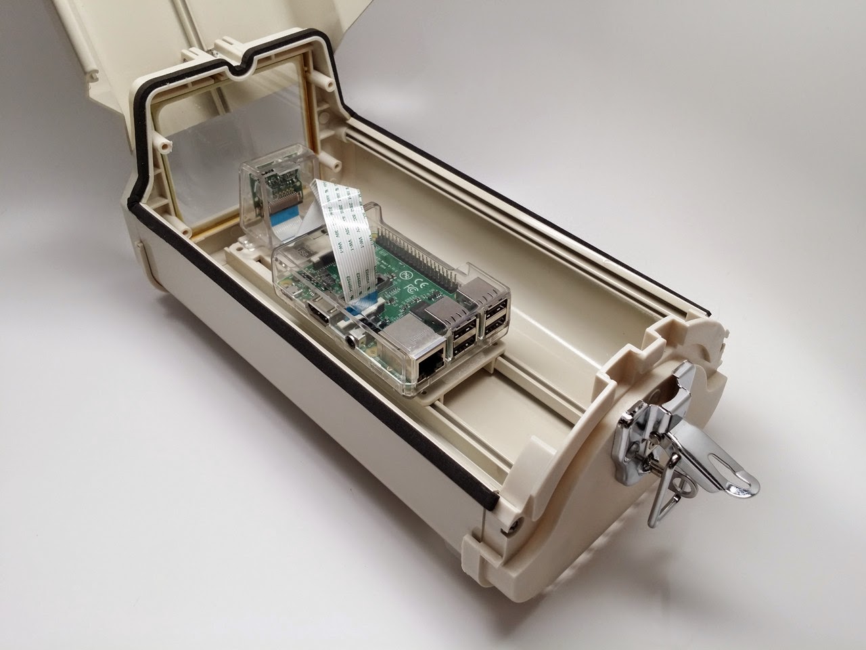
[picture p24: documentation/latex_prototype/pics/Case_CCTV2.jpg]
        
        \caption{Internal view.}
        \label{fig:CCTVCase2}
    \end{subfigure}
    \caption{Example CCTV enclosure re-purposed for a RPi2-based security system. Haldas, Mike. \href{https://plus.google.com/u/0/photos/+MikeHaldas/albums/6086069369593277953}{Raspberry Pi Outdoor Camera Housing.}}\label{fig:CCTVCase0}
\end{figure}

%---------------------------------------------------------------------
%           3D PRINT: RPI2
%---------------------------------------------------------------------
\subsection{Main System Enclosure}

After careful consideration, a unanimous decision to design custom weatherproof enclosures was made based on several reasons:

\begin{singlespace}
\begin{enumerate}
    \item A custom design would keep expenditure for enclosures within reasonable bounds. 
    \item The enclosure can be designed so that the gap will be minimal between the camera lens and the enclosure's protective glass cover.
    \item Separate enclosures can be designed: One for the RPi2 and one for the Night Vision board, allowing for modularity through various configurations (for example: two Night Vision Boards).
\end{enumerate}
\end{singlespace}

\begin{figure}[H]
    \centering
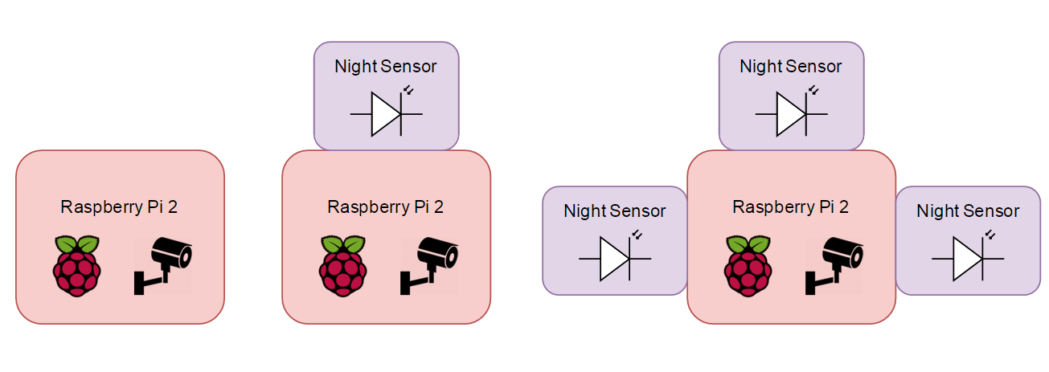
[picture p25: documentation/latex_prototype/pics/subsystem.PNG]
    \makebox[\textwidth][c]{}
    \caption{Various attachment configurations.}
    \label{fig:caseConfig}
\end{figure}

%\begin{figure}[H]
%    \centering
%    \begin{subfigure}[b]{0.475\textwidth}
%        \includegraphics[width=\textwidth]{pics/Case_RPi_Assembly.PNG}
%        \caption{Assembled view.}
%        \label{fig:RPiCase1}
%    \end{subfigure}
%    ~ %add desired spacing between images, e. g. ~, \quad, \qquad, \hfill etc. 
%      %(or a blank line to force the subfigure onto a new line)
%    \begin{subfigure}[b]{0.475\textwidth}
%        \includegraphics[width=\textwidth]{pics/Case_RPi_Exploded.PNG}
%        \caption{Exploded view.}
%        \label{fig:RPiCase2}
%    \end{subfigure}
%    \caption{CAD Model of the RPi2 outdoors enclosure.}\label{fig:RpiCase0}
%\end{figure}

The enclosures can be 3D printed for quick evaluation. The only possible issue with this method is sourcing the necessary o-rings and screws, but this won't likely be a real concern. Custom designing an enclosure for the Night Vision board improves the functionality of the Home Surveillance System during times low-ambient lighting. By focusing on modularity as a feature, each Nigh Vision enclosure will be able to mount on the top, left, and right sides of the RPi2 enclosure.

%---------------------------------------------------------------------
%           3D PRINT: NIGHT VISION
%---------------------------------------------------------------------
%\subsection{Night Vision Enclosure}

%Custom designing an enclosure for the Night Vision board improves the functionality of the Home Surveillance System during times low-ambient lighting. By focusing on modularity as a feature, each Nigh Vision enclosure will be able to mount on the top, left, and right sides of the RPi2 enclosure.

%\begin{figure}[H]
%    \centering
%    \begin{subfigure}[b]{0.475\textwidth}
%        \includegraphics[width=\textwidth]{pics/Case_RPi_Assembly.PNG}
%        \caption{Assembled view.}
%        \label{fig:LEDCase1}
%    \end{subfigure}
%    ~ %add desired spacing between images, e. g. ~, \quad, \qquad, \hfill etc. 
%      %(or a blank line to force the subfigure onto a new line)
%    \begin{subfigure}[b]{0.475\textwidth}
%        \includegraphics[width=\textwidth]{pics/Case_RPi_Exploded.PNG}
%        \caption{Exploded view.}
%        \label{fig:LEDCase2}
%    \end{subfigure}
%    \caption{CAD Model of the Night Vision outdoors enclosure.}\label{fig:LEDCase0}
%\end{figure}

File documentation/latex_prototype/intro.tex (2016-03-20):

\section{Introduction}
\label{sec:intro}

The Home Surveillance System is divided into two subsystems: a Raspberry Pi 2 with a camera module that performs computer vision and a night vision circuit comprised of an ambient light sensor and an array of IR LEDs. These two subsystems operate separately, allowing the user to be selective in their home monitoring configuration. %While custom enclosures are being developed that will allow both subsystems to couple

The Home Surveillance System--at its current iteration--is capable of detecting human through their frontal and side facial features. Motion detection runs continuously and acts as the idling state. Once motion is detected in the frame, the system isolates the sections. Finally, it seeks out human faces in the bounded through Haar-like features--a process pioneered by Viola-Jones \cite{ViolaJones}.

\begin{figure}[H]
    \centering
    \makebox[\textwidth][c]{}
    \caption{Remote access to the livestream through VNC.}
    \label{fig:remote}
\end{figure}

The user is able to view a livestream of the camera through an encrypted VNC connection, allowing for secure access within or without the home network. Figure \ref{fig:remote}, shows a screen shot of the proof of concept's livestream. This was taken from A. Martinez's laptop, which was connected to the RPi2 from an outside network.

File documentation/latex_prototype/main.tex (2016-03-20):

\documentclass[12pt]{article}
%\usepackage{fontspec}
%\usepackage[utf8]{inputenc}

\usepackage[margin=1in]{geometry}

\usepackage{graphicx}
\usepackage{amsmath}
\usepackage{float}
\usepackage{xfrac}
%\usepackage{subfig}
\usepackage{subcaption}
\captionsetup{belowskip=12pt,aboveskip=4pt}
\usepackage{booktabs}
\usepackage{enumitem}
\usepackage{csquotes}

\usepackage{amsmath}
\usepackage{mathptmx}
\usepackage{helvet}
\renewcommand{\familydefault}{\sfdefault}
\usepackage{varwidth}
\usepackage{verbatim}

\newenvironment{centerverbatim}{%
  \par
  \centering
  \varwidth{\linewidth}%
  \verbatim
}{%
  \endverbatim
  \endvarwidth
  \par
}

\usepackage{gensymb}
\usepackage{setspace}
\usepackage{booktabs}
\usepackage{hyperref}
\usepackage{tikz}
\usetikzlibrary{trees}

\usepackage{listings}
\usepackage{color}
\definecolor{rp}{rgb}{0.47, 0.32, 0.66}
\definecolor{rb}{rgb}{0.25, 0.41, 0.88}
\definecolor{tp}{rgb}{0.4, 0.01, 0.24}
\definecolor{lightgrey}{rgb}{0.9,0.9,0.9}
\definecolor{darkgreen}{rgb}{0,0.6,0}

%---------------------------------------------------------------------
%           FOOTER
%---------------------------------------------------------------------
\usepackage{fancyhdr}
\pagestyle{fancy}
\cfoot{Confidential $\mid$ ELEC4500-2016-PROTO Rev. 1}
\rfoot{\thepage}

\usepackage{multicol} % Required for splitting text into multiple columns
\setlength{\columnsep}{1cm}
\usepackage[toc]{glossaries}
\usepackage[protrusion=true,expansion=true]{microtype} % Improves spacing
%\usepackage[bf,sf,center]{titlesec} % Required for modifying section titles - bold, sans-serif, centered
%\usepackage{fancyhdr} % Required for modifying headers and footers
%\usepackage{subfiles}

\usepackage[toc,page]{appendix}

%\makeglossaries
%\input{./glossary.tex}

\begin{document}\thispagestyle{empty}
\pagenumbering{gobble}
\input{./title.tex}
\titleTMB
\newpage
\doublespacing

%----------------------------------------------------------------------
% Per S. Grenquist 2013 Publication RE: Senior Design Prototype Phase
%----------------------------------------------------------------------
%       Prototype Manufacturing Phase 
% After having all of their engineering calculations examined and
% certified, the students then start to build their prototype and
% design their production methods. 

%       Prototype 
% The culmination of the prototype Manufacturing phase is the 
% presentation of a working prototype. 

%       Production Design 
% The students also must provide a detailed description of the
% production process both for the prototype, as well as for larger
% production runs.

%      *Project Development*
% The Project Development section of each of the four phases of the
% BDS is used to assess how well the student group has progressed
% through the development of the project. The question asked at each
% of the developmental phases is whether the student design group is
% ahead of schedule and below budget. They're great for that section
% of the phase is dependent on how they answer that question. It is
% common to all of the four phases included in the PBDS.*

%----------------------------------------------------------------------
% WORD BANK
%----------------------------------------------------------------------
% eludicate

%----------------------------------------------------------------------
% Abstract and Table of Contents
%----------------------------------------------------------------------
\begin{abstract}\thispagestyle{empty}

A technical proof of concept for a lightweight, customizable, and scalable home surveillance system is presented in this documentation. This phase primarily of evaluating several object detection methods--in day and low ambient lighting conditions--for humans and vehicles. 
%Technical specifications, i.e. calculations, breadboard diagrams, schematics, PCB layout design, and program flowcharts for a Raspberry Pi 2-based home surveillance system is outlined in this document. This system is designed to allow a homeowner to record digital video--through low-ambient lighting environments--when an adjustable motion threshold is surpassed. The system will include human and vehicle detection features. Recorded videos will be cataloged by the object type that activated the camera, i.e. human, vehicle, and others. This proposed functionality will allow a homeowner to quickly access their database of video data through categorical ``bookmarks'' based on metadata such as date, time, and type of object. The result is a lightweight, customizable, and scalable home surveillance system that remains inexpensive for storage. 

\end{abstract}

\newpage

\tableofcontents
\listoffigures
\listoftables

\newpage

%---------------------------------------------------------------------
% Intro
%---------------------------------------------------------------------
\pagenumbering{arabic}

\addcontentsline{toc}{section}{\nameref{sec:intro}}
\input{intro}

\newpage
\addcontentsline{toc}{section}{\nameref{sec:creds}}
\input{creds}

\newpage
\addcontentsline{toc}{section}{\nameref{sec:pcb}}
\input{pcb}

\newpage
\addcontentsline{toc}{section}{\nameref{sec:human}}
\input{human}

\newpage
\addcontentsline{toc}{section}{\nameref{sec:enclosure}}
\input{enclosure}

\newpage
\addcontentsline{toc}{section}{\nameref{sec:challenge}}
\input{challenge}

\newpage
\addcontentsline{toc}{section}{\nameref{sec:projDev}}
\input{projDev}

%\newpage
%\addcontentsline{toc}{section}{\nameref{sec:directory}}
%\input{directory}

\newpage
%\begin{multicols}{2}
%\begin{onehalfspacing}
%\printglossary
%\end{onehalfspacing}
%\end{multicols}

%\newpage
%\section{Appendix}
%\pagenumbering{roman}

%\input{glossary}

\addcontentsline{toc}{section}{References}
\input{bibl}

\end{document}

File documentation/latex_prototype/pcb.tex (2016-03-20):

\section{Night Vision}
\label{sec:pcb}

\begin{figure}[H]
    \centering
    \makebox[\textwidth][c]{}
    \caption{Night Vision subsystem printed circuit boards.}
    \label{fig:pcbs}
\end{figure}

Figure \ref{fig:pcbs} shows the two custom PCBs for the IR LED arrays. These boards are completely separate from the main Computer Vision subsystem. This allows the user to position the Night Vision boards at locations of interest. For example, the user could position the Computer Vision subsystem above their front door and position one or more Night Vision subsystems near their vehicle or walkway. The flexibility of the Night Vision subsystem allows for greater customization to the end user, who can decide to either on-board, off-board, or not utilize the boards based on their needs.

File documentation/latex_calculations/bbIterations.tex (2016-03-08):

\section{Breadboard Prototyping Iterations}
\label{sec:bbIter}

Due to anticipated difficulties in driving the IR LEDs, there are several iterations of design choices for the system.

%---------------------------------------------------------------------
%   RPI2
%---------------------------------------------------------------------
\subsection{RPi2 GPIO-based Design}

In this design, an analog-to-digital (ADC) integrated circuit is added in order to transfer the data from the analog sensor to the RPi2.

\begin{figure}[H]
    \centering
    \makebox[\textwidth][c]{}
    \caption{Fritzing breadboard diagram of the RPi2 design.}
\end{figure}

%---------------------------------------------------------------------
%   ARDUINO
%---------------------------------------------------------------------
\subsection{Arduino-based Design}

The ``Arduino-based design'', in actuality, would be an Atmel AVR series microcontroller. In this design, the Arduino Uno Rev. 3--based on the ATmega328--is utilized as a quick evaluation on whether hosting the LEDs on a microcontroller (and subsequent 5V source) would better serve the purposes of night illumination for the camera. 

\begin{figure}[H]
    \centering
    \begin{subfigure}[b]{0.495\textwidth}
        
        \caption{Fritzing breadboard diagram.}
        \label{fig:BBUno1}
    \end{subfigure}
    ~ %add desired spacing between images, e. g. ~, \quad, \qquad, \hfill etc. 
      %(or a blank line to force the subfigure onto a new line)
    \begin{subfigure}[b]{0.45\textwidth}
        
        \caption{Physical breadboard prototype.}
        \label{fig:BBUno2}
    \end{subfigure}
    \caption{Prototyping the Night Vision block on an Arduino Uno Rev. 3.}\label{fig:BBUno}
\end{figure}

%---------------------------------------------------------------------
%   ATTINY85
%---------------------------------------------------------------------
\subsection{ATtiny85-based Design}

The latest iteration takes the Arduino-based design and ports it over to an ATtiny85 microcontroller. Manufacturing costing for 10,000 units is the primary rationale for this decision. Since the microcontroller would only be responsible for the light sensor and the LEDs, a microcontroller from the megaAVR family would be underutilized whereas one from the tinyAVR family contains all that is necessary to host the Night Vision block.

\begin{table}[H]
\centering
\caption{Comparison between microcontroller candidates for the Night Vision block.}
\label{mcuTable}
\begin{tabular}{@{}lrrr@{}}
\toprule
Microcontroller & \multicolumn{1}{c}{\begin{tabular}[c]{@{}c@{}}Program\\ Space\end{tabular}} & \multicolumn{1}{c}{I/O Pins} & \multicolumn{1}{c}{\begin{tabular}[c]{@{}c@{}}Price Per Unit \\ for 10K Units\end{tabular}} \\ \midrule
ATmega328       & 32K                                                                         & 23                           & 1.670                                                                                       \\
ATtiny85        & 8K                                                                          & 6                            & 0.748                                                                                       \\ \bottomrule
\end{tabular}
\end{table}

For the purposes of a manufacturing run, the cost of an ATtiny85 is also significantly less than utilizing an ADC IC to connect with the RPi2. With a design based on the ATtiny85, the RPi2 can focus solely on processing computer vision tasks.

\begin{table}[H]
\centering
\caption{Comparison between ADC IC candidates for the Night Vision block.}
\label{adcTable}
\begin{tabular}{@{}lrrr@{}}
\toprule
ADC     & \multicolumn{1}{c}{Resolution} & \multicolumn{1}{c}{Channels} & \multicolumn{1}{c}{\begin{tabular}[c]{@{}c@{}}Price Per Unit \\ for 10K Units\end{tabular}} \\ \midrule
MCP3008 & 10-bit                         & 8                            & 1.660                                                                                       \\
MCP3002 & 10-bit                         & 2                            & 1.350                                                                                       \\ \bottomrule
\end{tabular}
\end{table}

\begin{figure}[H]
    \centering
    \begin{subfigure}[b]{0.475\textwidth}
        
        \caption{Fritzing breadboard diagram.}
        \label{fig:BBTiny1}
    \end{subfigure}
    ~ %add desired spacing between images, e. g. ~, \quad, \qquad, \hfill etc. 
      %(or a blank line to force the subfigure onto a new line)
    \begin{subfigure}[b]{0.475\textwidth}
        
        \caption{Physical breadboard prototype.}
        \label{fig:BBTiny2}
    \end{subfigure}
    \caption{Prototyping the Night Vision block on an ATtiny85, first iteration.}\label{fig:BBTiny}
\end{figure}

\begin{figure}[H]
    \centering
    \makebox[\textwidth][c]{}
    \caption{Fritzing breadboard diagram of the ATtiny85 design, second iteration.}
\end{figure}

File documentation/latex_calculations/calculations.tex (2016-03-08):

\section{Calculations}
\label{sec:calc}
% CHANGE GB TO 1073741824 BYTES!!!

%----------------------------------------------------------------------
%           STORAGE
%----------------------------------------------------------------------
\subsection{Storage}

Storage requirements for 24 hours of 720p video data (.mp4):
\begin{equation*}
\begin{split}
Continual & = \left(\frac{24 \ hr}{1 \ day}\right)\left(\frac{60 \ min}{1 \ hr}\right)\left(\frac{60 \ sec}{ 1 \ min}\right)\left(\frac{17 \ mbit}{1 \ sec}\right)\left(\frac{1 \ byte}{8 \ bit}\right)\left(\frac{1 \ GB}{1737441824 \ byte}\right) \\
& = 170.99 \ \frac{GB}{day}
\end{split}
\end{equation*}

By limiting the active recording to moments where objects are detected, this storage requirement can be significantly lowered. Taking a theoretical family of 4 and a single dog, we can calculate for a minimum duration that the RPi2 is expected to record in 24 hours: 

\begin{table}[H]
\centering
\caption{Known sighting during an average 24 hour day for a front door camera.}
\label{floor_table}
\begin{tabular}{@{}lcccc@{}}
\toprule
Type     & Qty & Duration (min) & Sighting/24 hr & Total  \\ \midrule
Person   & 4   & 1              & 2               & 8      \\
Dog      & 1   & 1              & 2               & 2      \\
Delivery & 2   & 1              & 1               & 2      \\ \midrule
         &     &                &                 & 12 min
\end{tabular}
\end{table}

With a minimum recording duration of 12 minutes based on the expected sightings (detected objects), the floor data requirements per 24 hours becomes:

\begin{equation*}
\begin{split}
Floor \ & = \left(\frac{12 \ min}{1 \ day}\right)\left(\frac{60 \ sec}{ 1 \ min}\right)\left(\frac{17 \ Mbit}{1 \ sec}\right)\left(\frac{1 \ byte}{8 \ bit}\right)\left(\frac{1 \ GB}{1737441824 \ byte}\right) \\
& = 0.000014254 \ \frac{GB}{day}\Rightarrow 0.014254 \ \frac{MB}{day} \Rightarrow 14.254 \ \frac{KB}{day}
\end{split}
\end{equation*}

%----------------------------------------------------------------------
%           NODS
%----------------------------------------------------------------------
\subsection{Night Vision}

\subsubsection{Analog Light Sensor}

\begin{equation*}
\begin{split}
    \log\left(I_{O}\right) &= mx + b \\
    I_{O} &= m\log\left(x\right) + b \\
    I_{O} &= 10\log\left(E_{v}\right)\left[l_{x}\right]
\end{split}
\end{equation*}

The sensor has an output current range of $0\mu A$--$50\mu A$ between $1$ lux--$100000$ lux. The breakout board converts this current into a voltage using a $68K\Omega$ resistor, giving a voltage output of $0V$--$3.4V$. Given the use-case of the light sensor, the $3.4V$ can be approximated to $3.3V$, which is a suitable voltage reference for the ATtiny85 microcontroller. With the output current range approximated to a voltage range of $0V$--$3.3V$ between $1$ lux--$100000$ lux,

\begin{equation*}
\begin{split}
    log_{i} &= \log\left(l_{x \ MAX} - l_{x \ MIN}\right) \\
    &= \log\left(100000\right) = 5 \\
\end{split}
\end{equation*}

To convert the analog value to a digital value, an 8-bit ADC is used:
\begin{equation*}
    ADC = \frac{log_{i}}{1024 \ steps} = 0.00488
\end{equation*}

Finally, the formula to obtain the final lux output, $l_{xo}$, on the RPi2:

\begin{equation*}
%\begin{split}
    l_{xo} = 10^{raw_{i} \times ADC} = 10^{raw_{i} \times 0.00488}
%\end{split}
\end{equation*}

where $raw_{i}$ is the raw value received by one of the analog pins on the ATtiny85.\\

\begin{figure}[H]
    \centering
    \makebox[\textwidth][c]{}
    \caption{Voltage divider for sensor voltage reference.}
\end{figure}

Since 3.3V was chosen as the voltage reference value for the sensor, a voltage divider will be constructed in order to drop the 5V supply:

\begin{equation*}
    V_{1} = V_{CC} \frac{R_{2}}{R_{1} + R_{2}} = 5V \frac{3.3K\Omega}{1.7K\Omega + 3.3K\Omega} = 3.3V
\end{equation*}

%----------------------------------------------------------------------
%           LEDS
%----------------------------------------------------------------------
\subsubsection{Driving the LEDs}

\paragraph{Single LED Iteration}
The 8mm IR LEDs have a forward voltage drop of 1.3V and a current recommendation of 100mA. A resistor is added in series to each IR LED with the values chosen by:

\begin{equation*}
    R_{IR} = \frac{V_{CC} - V_{D}}{I_{D}} = \frac{5V - 1.3V}{100mA} = 37\Omega\approx 39\Omega
\end{equation*}

\begin{equation*}
    P_{D} = I_{D}^{2}R_{IR} = \left(100mA\right)^{2}\left(39\Omega\right) = 0.39W
\end{equation*}

\begin{figure}[H]
    \centering
    \makebox[\textwidth][c]{}
    \caption{Single LED circuit branch on the Night Vision block.}
\end{figure}

\paragraph{Series LED Iteration}
Another configuration that is being considered includes an additional IR LED onto each of the 3 ATtiny85 output pins. This changes the series resistor value to:

\begin{equation*}
    R_{IR} = \frac{V_{CC} - V_{D} - V_{D}}{I_{D}} = \frac{5V - 1.3V - 1.3V}{100mA} = 24\Omega\approx 27\Omega
\end{equation*}

\begin{equation*}
    P_{D} = I_{D}^{2}R_{IR} = \left(100mA\right)^{2}\left(27\Omega\right) = 0.27W
\end{equation*}

\begin{figure}[H]
    \centering
    \makebox[\textwidth][c]{}
    \caption{Double LED circuit branch on the Night Vision block.}
\end{figure}

%----------------------------------------------------------------------
%           CV PRE-PROCESSING
%----------------------------------------------------------------------
\subsection{Computer Vision: Pre-processing}

Before performing feature extraction, a given image--also known as a frame--is pre-processed in order to increase the accuracy of object-class detection. Some of these pre-processing steps also improve feature extraction during low-ambient light conditions. Some of these image processing techniques considers a given image in sections. This type of sectioning results in kernels, which is $m \times n$ matrix ``windows'' of a given frame. Convolution is then performed on the matrix, which averages all of the pixels around the center-most pixel. 

\begin{figure}[H]
    \centering
    \begin{subfigure}[b]{0.475\textwidth}
        
        \caption{Original image.}
        \label{fig:CalcEx0}
    \end{subfigure}
    ~ %add desired spacing between images, e. g. ~, \quad, \qquad, \hfill etc. 
      %(or a blank line to force the subfigure onto a new line)
    \begin{subfigure}[b]{0.475\textwidth}
        
        \caption{Converted to grayscale.}
        \label{fig:CalcEx1}
    \end{subfigure}
    \caption{An original image is converted to grayscale. A $3 \times 3$ matrix is then sectioned off for further pre-processing. A grid is used in (b) to show individual pixel boundaries.}\label{fig:CalcEx}
\end{figure}

\begin{figure}[H]
    \centering
    \makebox[\textwidth][c]{}
    \caption{The values for each pixel within the $3 \times 3$ matrix.}
    \label{fig:CalcEx2}
\end{figure}

As an arbitrary example, a $3 \times 3$ matrix in Fig. \ref{fig:CalcEx1}, bordered in red, will be considered for calculations.

%\begin{equation*}
%    118 + 90 + 57 + 105 + 69 + 59 + 167 + 113 + 63 = 841
%\end{equation*}

%----------------------------------------------------------------------
%           GAUSSIAN
%----------------------------------------------------------------------
\subsubsection{Gaussian Blurring}
% http://www.pixelstech.net/article/1353768112-Gaussian-Blur-Algorithm
% http://haishibai.blogspot.com/2009/09/image-processing-c-tutorial-4-gaussian.html
Blurring--also known as smoothing--is an image processing technique where high frequency noise is removed from a given image at the cost of detail reduction. For the purposes of this system, blurring will improve edge detection \cite[p.~28, 32]{mallat}.

Gaussian blurring was chosen due to its ability to utilize a weighted mean when averaging pixels in each frame. This specific blurring technique will allow for better performance when thresholding the frames. The name for this blurring technique comes from its use of a Gaussian function for calculations.

\begin{equation}
    G(x, y) = \frac{1}{\sqrt{2\pi\delta}}e^{-\frac{x^{2} + y^{2}}{2\delta^{2}}}
\end{equation}

Using the example arbitrary window in the previous section, each pixel is assigned a coordinate:

\begin{equation*}
    \begin{bmatrix}
        (-1, 1) & (0, 1) & (1, 1) \\
        (-1, 0) & (0, 0) & (1, 0) \\
        (-1, -1) & (0, -1) & (1, -1) 
    \end{bmatrix}
\end{equation*}

Choosing an arbitrary $\delta$ value of 1.5 the center coordinate is calculated through the Gaussian function:

\begin{equation*}
    G(0, 0) = \frac{1}{\sqrt{2\pi 1.5}}e^{-\frac{0^{2} + 0^{2}}{2 \times 1.5^{2}}} = 0.0707
\end{equation*}

Calculating the rest of the coordinates results in a weighted matrix:

\begin{equation*}
    \begin{bmatrix}
        \textcolor{rp}{0.0454} & \textcolor{rb}{0.0566} & \textcolor{rp}{0.0454} \\
        \textcolor{rb}{0.0566} & 0.0707 & \textcolor{rb}{0.0566} \\
        \textcolor{rp}{0.0454} & \textcolor{rb}{0.0566} & \textcolor{rp}{0.0454}
    \end{bmatrix}
\end{equation*}

The sum of those values becomes:

\begin{equation*}
        (0.0435 \times 4) + (0.0566 \times 4) + 0.0707 =  0.4787
\end{equation*}

Dividing by the summation will result in a weighted average matrix:

\begin{equation*}
    \frac{1}{0.479}
    \begin{bmatrix}
        \textcolor{rp}{0.0454} & \textcolor{rb}{0.0566} & \textcolor{rp}{0.0454} \\
        \textcolor{rb}{0.0566} & 0.0707 & \textcolor{rb}{0.0566} \\
        \textcolor{rp}{0.0454} & \textcolor{rb}{0.0566} & \textcolor{rp}{0.0454}
    \end{bmatrix}
    = 
    \begin{bmatrix}
        \textcolor{rp}{0.0948} & \textcolor{rb}{0.118} & \textcolor{rp}{0.0948} \\
        \textcolor{rb}{0.118} & 0.148 & \textcolor{rb}{0.118} \\
        \textcolor{rp}{0.0948} & \textcolor{rb}{0.118} & \textcolor{rp}{0.0948}
    \end{bmatrix}
\end{equation*}

Multiplying each coordinate of the $3 \times 3$ window will result in a Gaussian blur:

\begin{equation*}
    \begin{bmatrix}
        (118 \times 0.0948) & (90 \times 0.118)& (57 \times 0.0948) \\
        (105 \times 0.118) & (69 \times 0.148) & (59 \times 0.118)\\
        (167 \times 0.0948) & (113 \times 0.118) & (63 \times 0.0948) 
    \end{bmatrix}
    = 
    \begin{bmatrix}
        11.19 & 10.62 & 5.403 \\
        12.39 & 10.21 & 6.962 \\
        15.83 & 13.33 & 5.972 
    \end{bmatrix}
\end{equation*}

Finally, summing up the values from the last matrix will result in the new value for the center-most pixel.

\begin{equation*}
        11.19 + 10.62 + 5.403 + 12.39 + 10.21 + 6.962 + 15.83 + 13.33 + 5.972 = 91.907 
\end{equation*}

\begin{figure}[H]
    \centering
    \begin{subfigure}[b]{0.475\textwidth}
        
        \caption{Center pixel before Gaussian blur: 69.}
        \label{fig:CalcEx3}
    \end{subfigure}
    ~ %add desired spacing between images, e. g. ~, \quad, \qquad, \hfill etc. 
      %(or a blank line to force the subfigure onto a new line)
    \begin{subfigure}[b]{0.475\textwidth}
        
        \caption{Center pixel after Gaussian blur: 93.}
        \label{fig:CalcEx4}
    \end{subfigure}
    \caption{Comparison of pixel values between the original $3 \times 3$ window against one filtered with Gaussian blur.}\label{fig:CalcEx5}
\end{figure}

As Fig. \ref{fig:CalcEx4} shows, the resulting pixel value from a Gaussian blur performed in GNU Image Manipulation Program (GIMP) is within range of the calculated value.

\begin{equation*}
    \frac{\mid GIMP - Calculated\mid}{Calculated} \times 100\% = \frac{\mid93 - 91.907\mid}{91.907} \times 100\% = 0.0119\%
\end{equation*}

%----------------------------------------------------------------------
%           THRESH
%----------------------------------------------------------------------
%\subsubsection{Thresholding}

%----------------------------------------------------------------------
%           CV DETECTION
%----------------------------------------------------------------------
\subsection{Computer Vision: Detection}

Facial detection is performed by searching a given image for features based on black and white rectangles \cite{ViolaJones}. The calculation for the regions again uses matrix convolution.

The first step is a single pass through the entirety of a given image that computes the sum of all pixel values above and to the left ($+y, -x$) of the position being examined, inclusive. This is known as an integral table, that is:

\begin{equation}
    I_{\sum}\left(x, y\right) = \sum_{\substack{
   x'\leq x \\
   y'\leq y
  }} i(x', y')
\end{equation}

Using the original window in Fig. \ref{fig:CalcEx2}:

\begin{equation*}
    \begin{bmatrix}
        (i_{(-1, 1)} = 118) & (i_{(0, 1)} = 208) & (i_{(1, 1)} = 265) \\
        
        (i_{(-1, 0)} = 223) & (\ddots) & (\vdots)\\
        
        (i_{(-1, -1)} = 390) & (\cdots) & (i_{(1, -1)} = 841) 
    \end{bmatrix}
\end{equation*}

Feature identification is then performed using black and white rectangles over the integral table. The algorithm then passes feature types (various rectangles created by training the classifier using positive and negative results) over the integral table \cite{haarTri}. Identifying features from this point on is based on a simple summation of the rectangle corners:

\begin{equation}
    A_{M} = I(A) + I(C) - I(B) - I(D)
\end{equation}

\subsubsection{Haar}

The robustness of this method of object detection will be apparent with this final step. Consider Fig. \ref{fig:CalcHaar2}. 

\begin{figure}[H]
    \centering
    \begin{subfigure}[b]{0.475\textwidth}
        
        \caption{Haar line feature being applied to Fig. \ref{fig:CalcEx1}. Points A to D corresponds to the white rectangle's corners.}
        \label{fig:CalcHaar1}
    \end{subfigure}
    ~ %add desired spacing between images, e. g. ~, \quad, \qquad, \hfill etc. 
      %(or a blank line to force the subfigure onto a new line)
    \begin{subfigure}[b]{0.475\textwidth}
        
        \caption{Computing the leftmost white rectangle of Fig. \ref{fig:CalcEx1}'s integral image can be quickly achieved, allowing for real-time detection.}
        \label{fig:CalcHaar2}
    \end{subfigure}
    \caption{Facial detection through Haar-like features.}
    \label{fig:CalcHaar3}
\end{figure}

By analyzing the integral table of the original image, feature extraction becomes computationally inexpensive. If a $3 \times 3$ rectangle is covering the integral table that was solved earlier, the resulting calculation is:

\begin{equation*}
    A_{M} = I(A) + I(C) - I(B) - I(D) = 118 + 841 - 265 - 390 = 304
\end{equation*}
  
  This value is finally compared against the collection of rectangular Haar features collected during classifier training.
  
  Haar-like algorithm is grounded upon machine learning, a database of images containing positive and negative results for vehicles \cite{vehicleFeatures}. Since the detection algorithm based on Haar features is scale invariant, a set of images can then be used to train a Haar classifier for vehicles \cite{motionHaar}. This eliminates the use of blob analysis for vehicles.

%----------------------------------------------------------------------
%           ALGORITHMIC
%----------------------------------------------------------------------
%\subsection{Algorithmic Helper Functions}

%This section lists the calculations used in the software flowcharts.

%\subsubsection{Elapsed Time}

%\begin{equation*}
    
%\end{equation*}

%\newpage
%\begin{multicols}{2}
%\begin{onehalfspacing}
%\printglossary
%\end{onehalfspacing}
%\end{multicols}

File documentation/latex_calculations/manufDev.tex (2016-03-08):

\section{Project Development: Manufacturing}
\label{sec:manufDev}

The PCB layouts as shown below are currently being produced by Fritzing Fab. The estimated delivery date is mid-March.

\begin{figure}[H]
    \centering
    \makebox[\textwidth][c]{}
    \caption{PCB layout planning.}
    \label{tiny2_plan}
\end{figure}

\subsection{ATtiny85 Design: 3 LEDs}

\begin{figure}[H]
    \centering
    \makebox[\textwidth][c]{}
    \caption{Fritzing PCB layout of the first ATtiny85 design.}
    \label{tiny1_pcb}
\end{figure}

\subsection{ATtiny85 Design: 6 LEDs}

\begin{figure}[H]
    \centering
    \makebox[\textwidth][c]{}
    \caption{Fritzing PCB layout of the second ATtiny85 design.}
    \label{tiny2_pcb}
\end{figure}

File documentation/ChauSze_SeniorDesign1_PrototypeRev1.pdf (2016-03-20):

NELSON BAMFORD
SZE “RON” CHAU

ARIEL MARTINEZ

### ENGINEERING PROTOTYPE

– f or–
a Home Surveillance System

## WENTWORTH INSTITUTE OF TECHNOLOGY

### ELEC 4500: SENIOR ELECTRONIC DESIGN I

INSTRUCTOR: PROFESSOR GRENQUIST
SUBMISSION: REV. 1, 16MAR2016

Abstract

A technical proof of concept for a lightweight, customizable, and scalable home

surveillance system is presented in this documentation. This phase primarily of evalu-

ating several object detection methods–in day and low ambient lighting conditions–for

humans and vehicles.

CONTENTS | CONTENTS

## Contents

Introduction | 1
1 Introduction | 1
Prototype Specifications and Credentials | 2
2 Prototype Specifications and Credentials | 2
Night Vision | 3
3 Night Vision | 3
Facial Detection | 4
4 Facial Detection | 4
Enclosures | 8
5 Enclosures | 8
Challenges and Considerations | 11
6 Challenges and Considerations | 11
Confidential | ELEC4500-2016-PROTO Rev. 1

LIST OF FIGURES | LIST OF FIGURES
6.1.2 USB Current Limiter | 12
6.2 Security | 12
Project Development | 13
7 Project Development | 13
7.1 Anticipated Feature: Android App | 13
7.2 Anticipated Feature: Servos | 13
References | 14

## List of Figures

1 | Remote access to the livestream through VNC | | 1
2 | Night Vision subsystem printed circuit boards | | 3
3 | Indoor evaluation environment. The prototype is on the right edge of the
| TV stand. The white plastic bag is approximately 4 ft from it, and Nelson’s
| position is approximately 8 ft away | | 4
4 | Indoor facial detection evaluated through various head wear at approximately
| 3-4 ft distance | | 5
5 | Positive detection for three humans at different distances | | 6
6 | Positive facial detection at night, IR LEDs active | | 7
7 | Proto Armour Enclosure by MobileApp Systems | | 8
8 | Example CCTV enclosure re-purposed for a RPi2-based security system.
| Haldas, Mike. Raspberry Pi Outdoor Camera Housing. (https://plus.google.com/u/0/photos/+MikeHaldas/albums/6086069369593277953) | | 9
9 | Various attachment configurations | 10
10 | Concept UI for the Android app | 13
Confidential | ELEC4500-2016-PROTO Rev. 1

LIST OF TABLES | LIST OF TABLES

## List of Tables

1 | Software utilized within prototype | | 2
2 | Credentials to the prototype system | | 2
3 | Example average current draw of the Home Surveillance System with unre-
lated USB devices attached to the RPi2 unit | 11
Confidential | ELEC4500-2016-PROTO Rev. 1

1 INTRODUCTION

## 1 Introduction

The Home Surveillance System is divided into two subsystems: a Raspberry Pi 2 with a

camera module that performs computer vision and a night vision circuit comprised of an

ambient light sensor and an array of IR LEDs. These two subsystems operate separately,

allowing the user to be selective in their home monitoring configuration.

The Home Surveillance System–at its current iteration–is capable of detecting human

through their frontal and side facial features. Motion detection runs continuously and acts

as the idling state. Once motion is detected in the frame, the system isolates the sections.

Finally, it seeks out human faces in the bounded through Haar-like features–a process

pioneered by Viola-Jones [1].


Figure 1: Remote access to the livestream through VNC.

The user is able to view a livestream of the camera through an encrypted VNC connec-

tion, allowing for secure access within or without the home network. Figure 1, shows a

screen shot of the proof of concept’s livestream. This was taken from A. Martinez’s laptop,

which was connected to the RPi2 from an outside network.

Confidential | ELEC4500-2016-PROTO Rev. 1 | 1

2 PROTOTYPE SPECIFICATIONS AND CREDENTIALS

## 2 Prototype Specifications and Credentials

Table 1: Software utilized within prototype.

Technology Version | Type | License
Raspbian | Jessie | Raspberry Pi Linux OS Distro GPL v2
Python | 2.7 | General Purpose Language | Python Software Foundation
OpenCV | 3.0.0 | Computer Vision Library | BSD
TightVNC | 1.3.9-6.5 Virtual Computing Network | GPL v2
Weaved | 1.3-02 | Network Managing Platform | GPL v2

Table 2: Credentials to the prototype system.

Name | Type
scrying | RPi2 Hostname
constantine RPi2 Username
cv | Virtual Environment

3 NIGHT VISION

## 3 Night Vision


Figure 2: Night Vision subsystem printed circuit boards.

Figure 2 shows the two custom PCBs for the IR LED arrays. These boards are completely

separate from the main Computer Vision subsystem. This allows the user to position

the Night Vision boards at locations of interest. For example, the user could position the

Computer Vision subsystem above their front door and position one or more Night Vision

subsystems near their vehicle or walkway. The flexibility of the Night Vision subsystem

allows for greater customization to the end user, who can decide to either on-board,

off-board, or not utilize the boards based on their needs.

4 FACIAL DETECTION

## 4 Facial Detection

Haar Cascade Classifiers is the method chosen to detect human faces.

### 4.1 Indoors Facial Detection: Environment

The indoor evaluation environment was a 12x20 ft room. The room was lit with two

overhead, bare T5 fluorescent bulbs in parallel, outputting approximately 3500K neutral

white. The primary evaluation distance was 4 ft, however, 8 ft and 10 ft were also evaluated

for scale invariance.


Figure 3: Indoor evaluation environment. The prototype is on the right edge of the TV stand. The white plastic bag is approximately 4 ft from it, and Nelson’s position is approximately 8 ft away.

4.2 Indoors Facial Detection: Head Wear | 4 FACIAL DETECTION

### 4.2 Indoors Facial Detection: Head Wear


(a) Sunglasses. | (b) Hoodie and sunglasses. | (c) Baseball cap.


(d) Paratrooper beret. | (e) Advanced Combat Helmet. | (f) Shemagh.

Figure 4: Indoor facial detection evaluated through various head wear at approximately 3-4 ft distance.

### 4.3 Indoors Facial Detection: Distance

Figure 5 demonstrates that the system is able to detect human faces at 3 ft., 8 ft., and 10 ft.

The dog in the frame was disregarded as this specific evaluation only searched for human

faces.

4.4 Nighttime Facial Detection | 4 FACIAL DETECTION


Figure 5: Positive detection for three humans at different distances.

### 4.4 Nighttime Facial Detection

Low-ambient lighting conditions proved to be a formidable and admittedly underestimated

challenge. The success rate for human facial detection remains low, hovering around

20% with the 3-IR LED Night Vision board activated. The chance for a positive detection

increases when the distance from the Night Vision board decreases. At approximately 3 ft.,

the success rate increases to approximately 40%.

Plans to increase success rate includes:

1. Modifying the intensity of the IR LEDs.
2. Increasing the numbers of IR LEDs to the Night Vision board.
3. Increasing the numbers of Night Vision boards.

4.4 Nighttime Facial Detection | 4 FACIAL DETECTION


Figure 6: Positive facial detection at night, IR LEDs active.

5 ENCLOSURES

## 5 Enclosures

During the Proposal Phase the design included a MobileApp Systems Proto Armour

Enclosure for the RPi2. During cost analysis, it was quickly concluded that–while beneficial

at the proof of concept stage–this component would not meet the requirements for a

production-level product. The choice of the Proto Armour was based on the enclosure’s

robust aircraft-grade aluminum, support for the camera module, and numerous mounting

holes at each side of the case. The Proto Armour, however, wasn’t designed to be

weatherproof. In addition, the cost per enclosure at $45 per enclosure represents close

to 30% of the direct materials cost per unit. This high cost disqualified the Proto Armour

Enclosure for purposes beyond proof of concept designs.


(a) External view. | (b) Internal view.

Figure 7: Proto Armour Enclosure by MobileApp Systems.

### 5.1 CCTV Weatherproof Enclosure

A strong contender was a generic 15 in. length CCTV Weatherproof Enclosure. This enclo-

sure is primarily aluminum is sealed with heavy duty rubber to prevent water intake. Priced

around $25, this enclosure is an improvement from the Proto Armour. This candidate,

however, was rejected for several reasons:

5.2 Main System Enclosure | 5 ENCLOSURES
1. Enclosure is larger and heavier than necessary for the system, making inconspicuous installation unlikely.
2. The large viewing window and the distance where the camera is mounted increases light pollution from the surrounding environment as well as the RPi2 diagnostic LEDs.
3. LEDs inside: The viewing window isn’t wide enough for both the camera module and Night Vision board.
4. LEDs outside: A secondary enclosure will be required to custom mount onto the CCTV enclosure.
5. While not required, additional enclosures for the RPi2 and the camera module would be recommended, thereby increasing the cost to the level of the Proto Armour Enclosure.


(a) External view. | (b) Internal view.

Figure 8: Example CCTV enclosure re-purposed for a RPi2-based security system. Haldas, Mike. Raspberry Pi Outdoor Camera Housing. (https://plus.google.com/u/0/photos/+MikeHaldas/albums/6086069369593277953)

### 5.2 Main System Enclosure

After careful consideration, a unanimous decision to design custom weatherproof enclo-

sures was made based on several reasons:

1. A custom design would keep expenditure for enclosures within reasonable bounds.

5.2 Main System Enclosure | 5 ENCLOSURES
2. The enclosure can be designed so that the gap will be minimal between the camera lens and the enclosure’s protective glass cover.
3. Separate enclosures can be designed: One for the RPi2 and one for the Night Vision board, allowing for modularity through various configurations (for example: two Night Vision Boards).


Figure 9: Various attachment configurations.

The enclosures can be 3D printed for quick evaluation. The only possible issue with this

method is sourcing the necessary o-rings and screws, but this won’t likely be a real concern.

Custom designing an enclosure for the Night Vision board improves the functionality of the

Home Surveillance System during times low-ambient lighting. By focusing on modularity

as a feature, each Nigh Vision enclosure will be able to mount on the top, left, and right

sides of the RPi2 enclosure.

6 CHALLENGES AND CONSIDERATIONS

## 6 Challenges and Considerations

### 6.1 Power and USB Current Draw

It is recommended to power the system with a 5V, 2A microUSB cable power supply. Using

a power supply with lower current capabilities will result in instability.

### 6.1.1 USB Hub

In addition to the 2A power supply consideration, end users that plan on attaching unrelated

USB devices could potentially experience intermittent wifi connection, amongst other

issues. Current draw from various USB devices was examined through the usb-devices

and lsusb -v commands in Raspbian:

Table 3: Example average current draw of the Home Surveillance System with unrelated USB devices attached to the RPi2 unit.

Device | Current Draw
Raspberry Pi | 750mA
Camera Module | 100mA–260mA
Wifi Dongle | 50mA–100mA
Keyboard and Mouse Combo | 98mA
External Hard Drive | 750mA

While it might seem okay to run the RPi2 off of a 5V, 2A power supply, this might not be

the case depending on additional USB devices unrelated to the home surveillance system.

For example, a user could attach some or all of the USB devices listed in Table 3. The

result is an average 1.96A current draw. Without a powered hub, this setup would risk wifi

stability when the user leverages the VNC server. A powered USB hub isn’t necessary at

the current design iteration, however, it is advised to consider one if there are plans to run

other USB-based, current-hungry devices on the RPi2 unit.

6.2 Security | 6 CHALLENGES AND CONSIDERATIONS

### 6.1.2 USB Current Limiter

The RPi2 includes a current limiter for USB peripherals to reduce brown-outs on the

main supply. The total current drawn by USB devices defaults to 600mA, but this can be

increased to 1.2A, doubling the default allowance. The RPi2 proof of concept unit scrying

has been adjusted for this increase. This adjustment is found in /boot/config.txt:

max_usb_current=1

Increasing this current limit seems to result in a more stable wireless connection for

remote viewing through VNC. If power-related issues occur (as indicated by the flickering

red power LED on the RPi2), commenting the line out of the file should be the first step in

debugging the issue.

### 6.2 Security

The current design relies on VNC to access the RPi2 desktop remotely. The initial process

to VNC from an outside network required port forwarding to a specific TCP port. This

method presents a security vulnerability; by default, the transmitted data isn’t encrypted.

This becomes a concern when accessing the system outside of the home network.

Weaved, a cloud-based network platform, was chosen as a safeguard for secure access

through VNC and HTTP [2].

7 PROJECT DEVELOPMENT

## 7 Project Development

### 7.1 Anticipated Feature: Android App

An Android app to view the livestream would greatly increase the accessibility of the Home

Surveillance System. This feature was tentatively announced during the Proposal Phase,

but time constraints limited the resources available for Android development. As a result,

the Android app is currently on hold until the next major iteration of the system.


Figure 10: Concept UI for the Android app.

### 7.2 Anticipated Feature: Servos

User-controlled pan-tilt movements is a planned feature for the next major iteration of the

Home Surveillance System. The tentative plan is to allow users to control the system

through the website livestream as well as through the planned Android app.

REFERENCES | | REFERENCES

## References

[1] P. Viola, M. Jones, “Robust Real-Time Face Detection,” in Int. Jour. Computer Vision, vol. 57.2, pp. 137-154, 2004.
[2] “Raspberry Pi - Weaved Inc”, | Weaved Inc., | 2016. [Online]. Available:
http://www.weaved.com/raspberry-pi-remote-connection/. [Accessed: 14MAR2016].

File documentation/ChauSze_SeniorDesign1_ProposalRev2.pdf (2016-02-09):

NELSON BAMFORD
SZE “RON” CHAU

ARIEL MARTINEZ

### ENGINEERING PROPOSAL

– f or–
a Home Surveillance System

## WENTWORTH INSTITUTE OF TECHNOLOGY

### ELEC 4500: SENIOR ELECTRONIC DESIGN I

INSTRUCTOR: PROFESSOR GRENQUIST
SPRING 2016

Table 1: Revision history.

Senior Electronic Design Proposal | Document Number: ELEC4500–2016
Rev. Description of Change | § Affected | Originator
01 | Initial Release | All | N. Bamford, R. Chau, A. Martinez

02

General Proofreading
Add Glossary and Calculations
Add Fig. 6–9
Revise Fig. 5, Sec. 6 & References
All | R. Chau
Confidential | ELEC4500–2016 Rev. 2

Abstract

A low-cost, low-maintenance, Raspberry Raspberry Pi 2-based home surveillance

system is proposed in this document. This system is designed to allow a homeowner

to record digital footage–through low-ambient environments–when a motion threshold

is surpassed. The system will include basic human detection and object recognition

features, and the recorded instance cataloged by the object that activated the camera,

e.g. human, vehicle, and others. This proposed functionality will allow a homeowner

to quickly access the database of footage through categorical “bookmarks” based on

metadata such as date, time, and type of object.

CONTENTS | CONTENTS

## Contents

1 Problem Statement and Motivation | 1
2 Background | 2
3 Proposed Solution | 8
4 Risks and Challenges | 13
5 Bill of Materials | 14
6 Division of Labor | 15
Confidential | ELEC4500–2016 Rev. 2

CONTENTS | CONTENTS
7 Evaluation Methods | 19
8 Conclusion | 20
Calculations | i
Glossary | ii
References | iv
Confidential | ELEC4500–2016 Rev. 2

LIST OF FIGURES | LIST OF TABLES

## List of Figures

1 | Haar-like cascade algorithm used to detect human faces | | 3
2 | Verizon Canary system | | 5
3 | Comcast Xfinity Homes system | | 6
4 | ADT Pulse system | | 7
5 | High level block diagram of proposed monitoring system | | 8
6 | Website mockup: livestream, daytime | | 9
7 | Website mockup: livestream, nighttime | | 9
8 | Website mockup: History of detected objects | 10
9 | Website mockup: Data visualization | 10
10 | Raspberry Pi 2 Model B (top) encased with a camera module | 11
11 | LAMP architecture for web application | 12
12 | Progress as of 07 JAN, 2016, broken up by sprints | 15

## List of Tables

1 | Revision history |
2 | Raspberry Pi 2 specifications | 12
3 | Comparison of major features from commercial systems | 13
4 | Prototyping bill of materials | 14
5 | Known sightings during an average 24 hour day for a front door camera. . . | i
Confidential | ELEC4500–2016 Rev. 2

1 PROBLEM STATEMENT AND MOTIVATION

## 1 Problem Statement and Motivation

Newton, Massachusetts is constantly rated as one of the safest cities in the country; that

doesn’t mean that crime doesn’t occur in the city [1]. At a localized point of view, one of the

engineers on this project–a resident of Newton–accumulated numerous experiences that

required the actions of Newton Police Department. In 2015, the neighbor of this engineer

had their house broken into. Thieves kicked in the back door; no one noticed the incident. A

few months later, Newton Police was called upon to dust (for fingerprints) a family members

work van after it was broken into for tools. On the week of Christmas, the garage of another

neighbor was broken into overnight. This neighbor was restoring a classic muscle car, and

the progress was halted due to stolen rare parts. The worst incident, however, happened a

few years ago to the engineers friend that was–at the time–living in West Newton. It was a

home invasion where the homeowner was tied up at gunpoint, and the thieves tossed her

dog into a closet before leaving with jewelry and a safe. To this day the perpetrators were

never caught.

The constraints of this device, as determined by informal surveying of Newton home-

owners, include the ability to determine if there is an object in motion near a home entrance

and to capture a video if this criteria is met. A secondary requirement requested asks

for the design of a method to distinguish a human from other objects such as vehicles,

and to create a metadata sorting method based on these identification criteria alongside

date/time.

The design must take these traits into consideration, or else the system would be

severely handicapped and similar to existing commercial systems. The proposed home

surveillance system acts as an affordable, mobile, and open source bridge between

available, albeit expensive commercial products that either secures empty homes or

monitor internal dwellings.

Confidential | ELEC4500–2016 Rev. 2 | 1

2 BACKGROUND

## 2 Background

Literary research for this design split into two distinct avenues: Computer vision and a

novelty investigation into currently available commercial solutions.

### 2.1 Computer Vision

The development of an image processing technique that fits our objectives involves object

recognition within the field of computer vision. Computer vision is the science of imagery

acquisition and interpretation through the use of computers [2, p. 1-5]. Object recognition

describes the task of locating, or recognizing, specific objects within images. In the case

of our design, object recognition tasks could be incorporated to evaluate initial images

arriving from a camera unit for identification of humans or vehicles. The object recognition

methods that are currently being considered includes Haar-like features and blob detection.

### 2.1.1 Haar-like Features

Haar-like features gets their namesake due to similarities to Haar wavelet transforms. It

is an object recognition algorithm that seeks out common patterns by calculating spatial

relationships of information (such as contrast) of the target object [3, p. 1]. These patterns

that the Haar-like algorithm checks are rectangular features that specific objects all have,

such as the distance between a humans eyes, or nose. As human recognition is an

important feature in the proposed system, a Haar-based facial detection algorithm will be

investigated for the prototype.

2.1 Computer Vision | 2 BACKGROUND


Figure 1: Haar-like cascade algorithm used to detect human faces.

### 2.1.2 Blob Detection and Analysis

Blobs refer to regions of similar pixels in an image. Blob algorithms locates these regions

and assigns a category to it based on light or color values [4, p. 8-18]. This method requires

segmentation of the target image, which involves in the removal of everything outside the

region of interest. Depending on the target environment, blob analysis is subject to noise

in the form of mis-categorized blobs. The deployment of a blob analysis algorithm would

require significant pre-processing of our target object. The advantage of utilizing blob

detection, however, includes simple identification of large, single-color dominant objects

such as vehicles. Due to this capability, blob detection will be one of the algorithms used

for the prototype. Of concern is the dependability of blob detection during low ambient

conditions.

2.2 Novelty Investigation | 2 BACKGROUND

### 2.2 Novelty Investigation

The investigation focused on three major companies with home monitoring commercial

solutions. Verizon and Comcast have indoor and outdoor cameras that provide a wireless

security system capable with live stream alongside phone apps. This is something that

the team aims to pursue (time-dependent). For the proposed system, it is important

that the final design remains cost efficient, and the main feature to implement–object

detection alongside an alert system–is something that current commercial products haven’t

introduced to the market. Looking at companies that supply commercial home surveillance

systems, the team wanted to identify:

- Patterns of features.
- Whether the plan comes with a subscription.
- Installation cost, if any.
- Cost of the physical equipment.
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

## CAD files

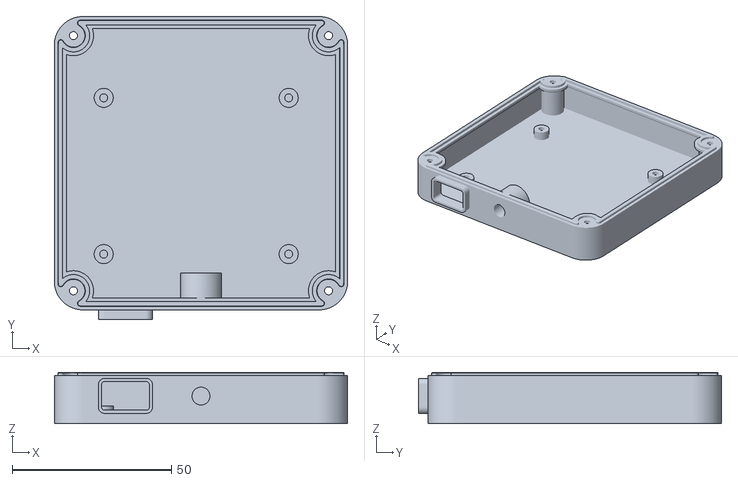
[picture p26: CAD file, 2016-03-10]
enclosures/nv_enclosure/Bottom-plate-mb.stl
92.0 x 95.0 x 16.0

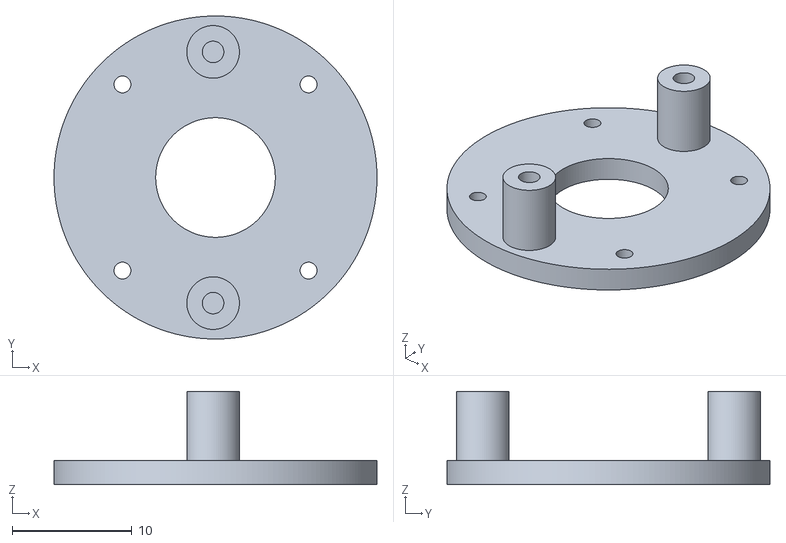
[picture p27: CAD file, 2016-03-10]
enclosures/rpi_enclosure/BamfordNelson_Case_RPi_Seal.STL
27.0 x 27.0 x 7.80

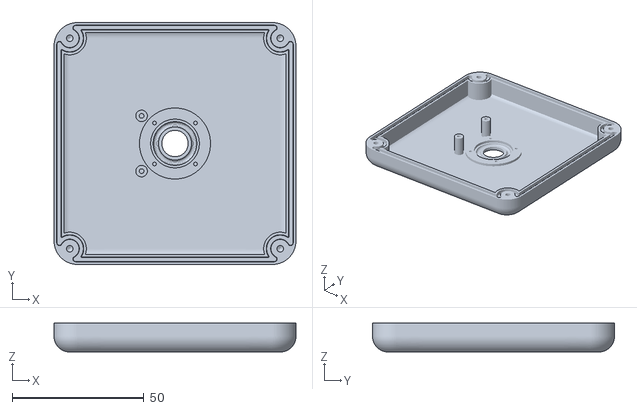
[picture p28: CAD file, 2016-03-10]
enclosures/nv_enclosure/Top-box-mb.stl
92.0 x 92.0 x 11.0

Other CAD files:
enclosures/nv_enclosure/seal-mb.stl
enclosures/rpi_enclosure/BamfordNelson_Case_RPi_Bottom.STL
enclosures/rpi_enclosure/BamfordNelson_Case_RPi_Top.STL

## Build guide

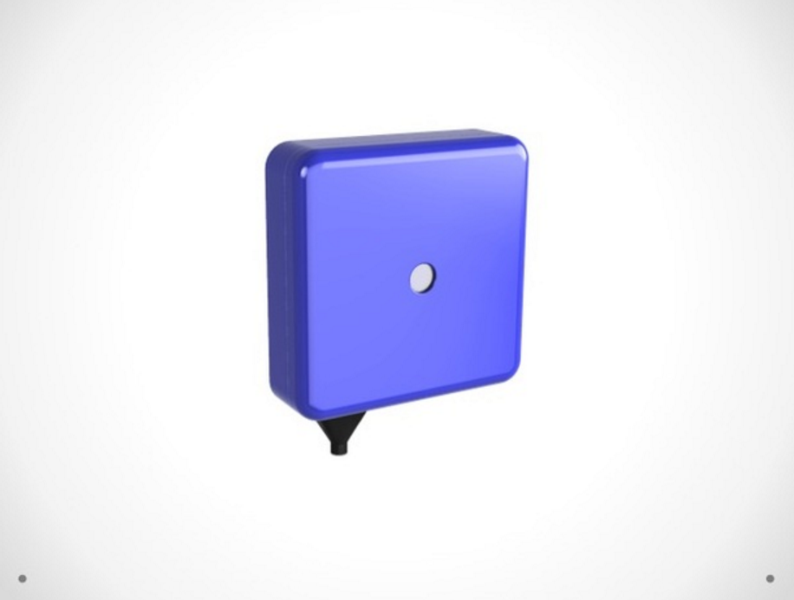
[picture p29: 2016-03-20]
documentation/latex_prototype/pics/Case_RPi_Assembly.PNG

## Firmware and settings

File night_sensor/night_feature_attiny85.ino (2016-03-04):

/*
@author:     Sze 'Ron' Chau
@source:     https://github.com/wodiesan/senior_design_spring
@Desc:       Adafruit Analog Light Sensor, modified by Ron Chau.
@Misc:       This version uses a stand-alone ATtiny85.

 1. Connect sensor output to Analog Pin 1
 2. Connect 5v to VCC and GND to GND
 3. Connect 3.3v to the AREF pin
*/

int led1 = 1;          // LED connected to digital pin 1 (physical pin 6)
int led2 = 3;          // LED connected to digital pin 3 (physical pin 2)
int led3 = 4;          // LED connected to digital pin 4 (physical pin 3)
int sensorPin = A1;    // Sensor connected to pin A1 (phys pin 7)

float rawRange = 1024; // 3.3v
float logRange = 5.0; // 3.3v = 10^5 lux

// Clear day sunset value chosen to test light sensing feature.
float lightLimit = 300;

void setup()
{
  analogReference(EXTERNAL); //
  //Serial.begin(9600);
  //Serial.println("Adafruit Analog Light Sensor Test");

  // LED pins
  pinMode(led1, OUTPUT);
  pinMode(led2, OUTPUT);
  pinMode(led3, OUTPUT);
}

void loop()
{
  // Read the raw value from the sensor:
  int rawValue = analogRead(sensorPin);
  int luxValue = (RawToLux(rawValue));

  delay(1000);

  // LEDS on if lux less than or equal.
  if(luxValue <= lightLimit){
    digitalWrite(led1, HIGH);   // LEDs on
    digitalWrite(led2, HIGH);
    digitalWrite(led3, HIGH);
  }
  else{
    digitalWrite(led1, LOW);   // LEDs off
    digitalWrite(led2, LOW);
    digitalWrite(led3, LOW);
  }
}

float RawToLux(int raw)
{
  float logLux = raw * logRange / rawRange;
  return pow(10, logLux);
}

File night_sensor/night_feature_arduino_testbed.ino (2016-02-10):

"""
@author:     Sze 'Ron' Chau
@source:     https://github.com/wodiesan/senior_design_spring
@Desc:       Adafruit Analog Light Sensor, modified by Ron Chau.

 1. Connect sensor output to Analog Pin 0
 2. Connect 5v to VCC and GND to GND
 3. Connect 3.3v to the AREF pin 
"""
 
int led1 = 2;          // LED connected to digital pin 2
int led2 = 3;          // LED connected to digital pin 3
int led3 = 4;          // LED connected to digital pin 4
int sensorPin = A0;    // select the input pin for the potentiometer
 
float rawRange = 1024; // 3.3v
float logRange = 5.0; // 3.3v = 10^5 lux

// Random value chosen to test light sensing feature.
float lightLimit = 600;

void setup() 
{
  analogReference(EXTERNAL); //
  Serial.begin(9600);
  Serial.println("Adafruit Analog Light Sensor Test");
  
  //LEF pins
  pinMode(led1, OUTPUT);
  pinMode(led2, OUTPUT);
  pinMode(led3, OUTPUT);
}
 
void loop() 
{
  // read the raw value from the sensor:
  int rawValue = analogRead(sensorPin);    
  Serial.print("Raw = ");
  Serial.print(rawValue);
  Serial.print(" - Lux = ");
  
  Serial.println(RawToLux(rawValue));

  // LEDS on if rawValue greater or equal.
  if(rawValue <= 400){
    digitalWrite(led1, HIGH);   // LED on
    digitalWrite(led2, HIGH);   
    digitalWrite(led3, HIGH);   
  }
  else{
    digitalWrite(led1, LOW);   // LEDs off
    digitalWrite(led2, LOW);   
    digitalWrite(led3, LOW);   
  } 
  delay(1000);
  
}
 
float RawToLux(int raw)
{
  float logLux = raw * logRange / rawRange;
  return pow(10, logLux);
}

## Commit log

2016-02-10 Add basic GA1A12S202 light sensor Arduino testbed.
2016-02-10 Create initial night sensor code for Pi
2016-03-06 Remove 2nd frame from haarDebug.
2016-03-08 Add Fritzing circuit designs and Calculations paper.
    [ChauSze_SeniorDesign1_BBTiny1.fzz, ChauSze_SeniorDesign1_BBTiny1_BB.fzz, ChauSze_SeniorDesign1_BBTiny1_PCB.fzz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]
2016-03-10 Add RPi A+ RainBerry case files.
    [Bottom-plate-mb.stl, Top-box-mb.stl, seal-mb.stl]
2016-03-10 Create working STL copies of RPi2 case.
    [BamfordNelson_Case_RPi_Bottom.STL, BamfordNelson_Case_RPi_Seal.STL, BamfordNelson_Case_RPi_Top.STL]
2016-03-11 Create LED case directory.
    [Top-box-mb-demo.stl]
2016-03-20 Begin open source organization. Create setup.py and /scrying/.
    [BamfordNelson_Case_RPi_Bottom.STL, BamfordNelson_Case_RPi_Seal.STL, BamfordNelson_Case_RPi_Top.STL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]
2016-03-20 Remove unused jpegs from hog svm folder. Consolidate enclosures into one folder.
    [BamfordNelson_Case_RPi_Bottom.STL, BamfordNelson_Case_RPi_Seal.STL, BamfordNelson_Case_RPi_Top.STL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]
2016-03-21 Adjust scrying.py for minor errors.
    [scrying.py]
2016-03-21 Fix command-line option warnings.
    [scrying.py]
2016-03-21 Begin multi-threading process. Create util camera functions.
2016-03-22 Add exception handling for camera init process.
2016-03-25 Pre-multithreading the camera stream.
2016-03-26 Add path to access cv2 in thread_cam sandbox.

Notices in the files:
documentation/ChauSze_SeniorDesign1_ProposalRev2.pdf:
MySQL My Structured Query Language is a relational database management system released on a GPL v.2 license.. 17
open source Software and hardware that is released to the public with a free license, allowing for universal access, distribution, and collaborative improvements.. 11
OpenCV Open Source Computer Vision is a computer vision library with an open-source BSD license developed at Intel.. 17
